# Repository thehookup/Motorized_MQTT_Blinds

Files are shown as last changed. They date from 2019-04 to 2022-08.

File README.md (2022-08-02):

# Motorized_MQTT_Blinds

I forked to add a couple of other base sizes. This is a great project to get the idea of how things work, but the contollers weren't staying connected with my HomeAssistant instance. I ultimately use the hardware from this repo with [Tasmota](https://github.com/tasmota/tasmotizer) configured in [Cover mode](https://tasmota.github.io/docs/Blinds-and-Shutters/#using-stepper-motors) instead. The instructions look daunting, but it takes longer to read than to set up, and it's been running rock solid for months now...

Make sure you use 2208's for noise control, otherwise you can have a rude awakening!

This repository is to accompany my Motorized_MQTT_Blinds video:

IMAGE ALT TEXT HERE (https://www.youtube.com/watch?v=1O_1gUFumQM)

## Parts List
Stepper Motors: https://amzn.to/2D5rVsF

Stepper Drivers: https://amzn.to/2OZqW1W

NodeMCU: https://amzn.to/2I89xDF

12V Power Supply: https://amzn.to/2G2ZJrf

Buck Converter: https://amzn.to/2UsQ7jA

## 3D Printing

Download the correct STL file for your style of tilt rod

## Wiring Schematic

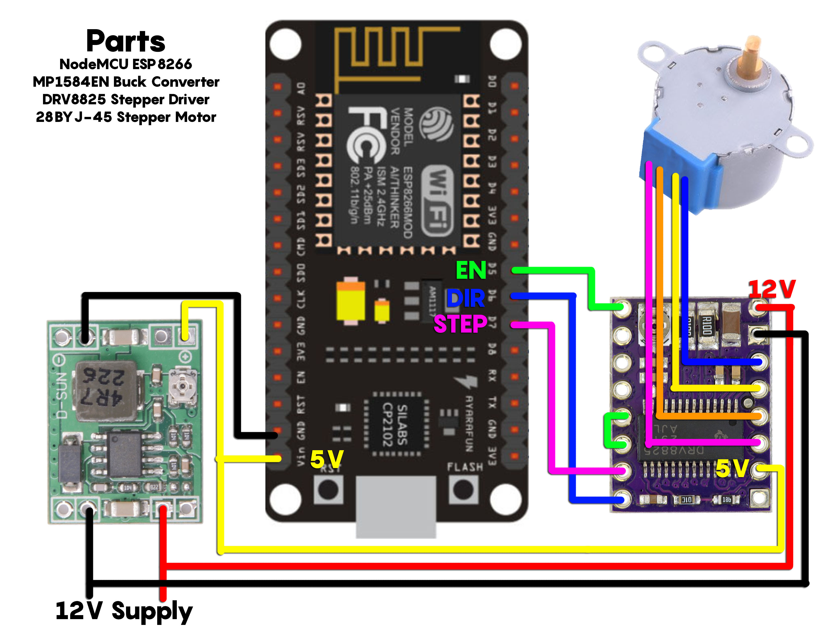
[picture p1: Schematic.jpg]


**Dont forget to cut the center trace on the stepper motor as shown in the youtube video**

## File setup

Fill out the entire USER CONFIGURATION section of the code.

You should leave "STEPS_TO_CLOSE" at 12 to start with.  It can be adjusted for your specific blinds

## Home Assistant YAML

Replace "BlindsMCU" with your MQTT_CLIENT_ID if you changed it in the file setup

Home Assistant 2022.7.5 and Later:
```yaml
mqtt:
  cover:
    - name: "BlindsKitchen"
      command_topic: "BlindsMCU/blindsCommand"
      position_topic: "BlindsMCU/positionState"
      set_position_topic: "BlindsMCU/positionCommand"
      retain: true
      payload_open: "OPEN"
      payload_close: "CLOSE"
      payload_stop: "STOP"
      position_open: 0
      position_closed: 12
```

Home Assistant 2022.6.5 and Earlier:

```yaml
cover:
  - platform: mqtt
    name: "Motorized Blinds"
    command_topic: "BlindsMCU/blindsCommand"
    set_position_topic: "BlindsMCU/positionCommand"
    position_topic: "BlindsMCU/positionState"
    retain: true
    payload_open: "OPEN"
    payload_close: "CLOSE"
    payload_stop: "STOP"
    position_open: 0
    position_closed: 12
  ```
  
## Optional - PCB Design for 3 blind system

Project File: 

GERBER FILE:Sender Board: https://github.com/thehookup/Motorized_MQTT_Blinds/blob/master/THU_Sender_Board.zip

GERBER FILE:Receiver Board: https://github.com/thehookup/Motorized_MQTT_Blinds/blob/master/THU_Receiver_Board.zip

## User Submitted PCBs

GERBER FILE: Dave Morris Quad Blind: https://github.com/thehookup/Motorized_MQTT_Blinds/blob/master/Dave_Morris_4_Blind_With_Power.zip

GERBER FILE:Joshua Garrison Single Blind: https://github.com/thehookup/Motorized_MQTT_Blinds/blob/master/Joshua_Garrison_Single_Blind.zip
  
## Recommended Tools

Ender3 3d Printer: https://amzn.to/2GcznnZ

Dupont Crimper and Connector Set: https://amzn.to/2X1Oeap

## Alexa only support available in the releases tab of this repo!

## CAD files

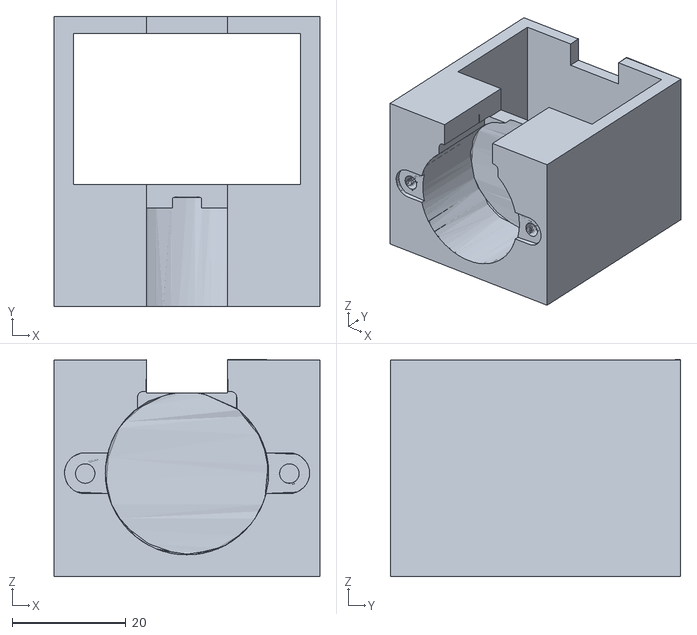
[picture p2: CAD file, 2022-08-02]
BlindsBaseShort.stl
46.8 x 51.1 x 38.2

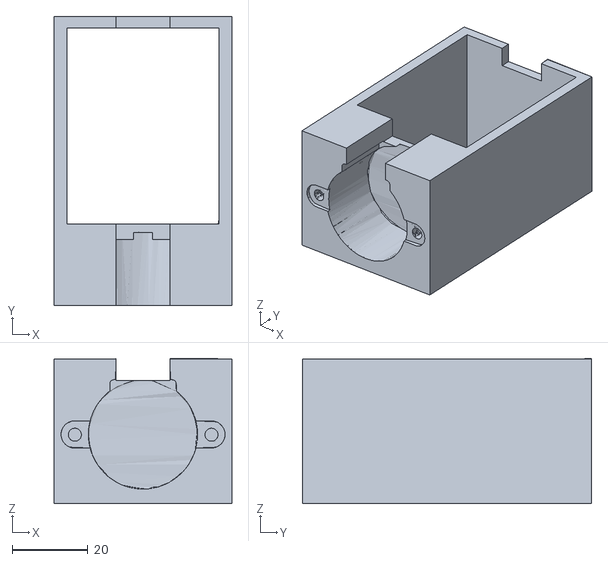
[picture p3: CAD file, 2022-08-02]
BlindsBaseShortLong.stl
46.8 x 76.1 x 38.2

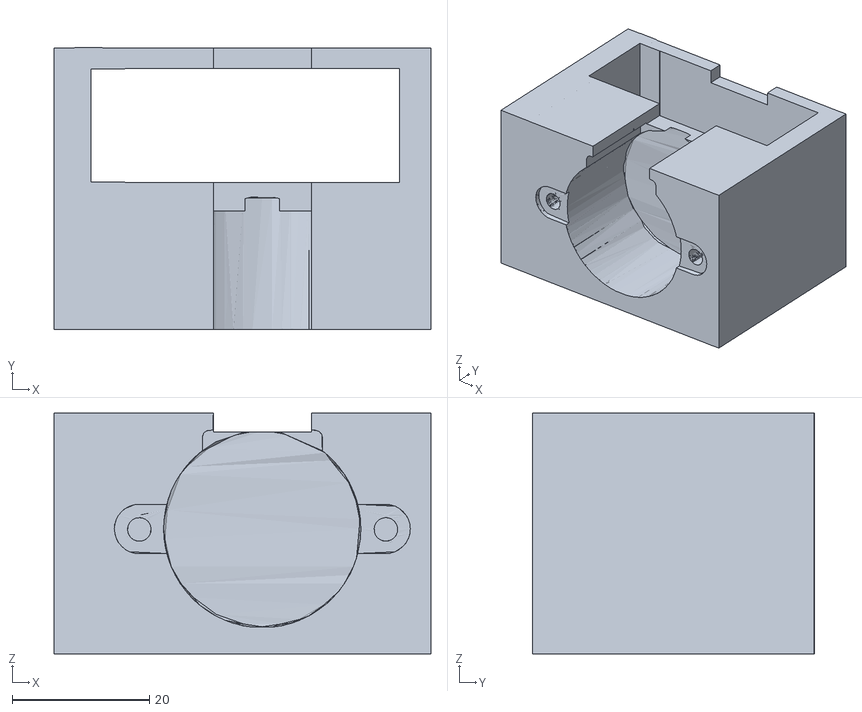
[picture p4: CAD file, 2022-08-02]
123jaloezie-base.stl
55.0 x 41.2 x 35.1

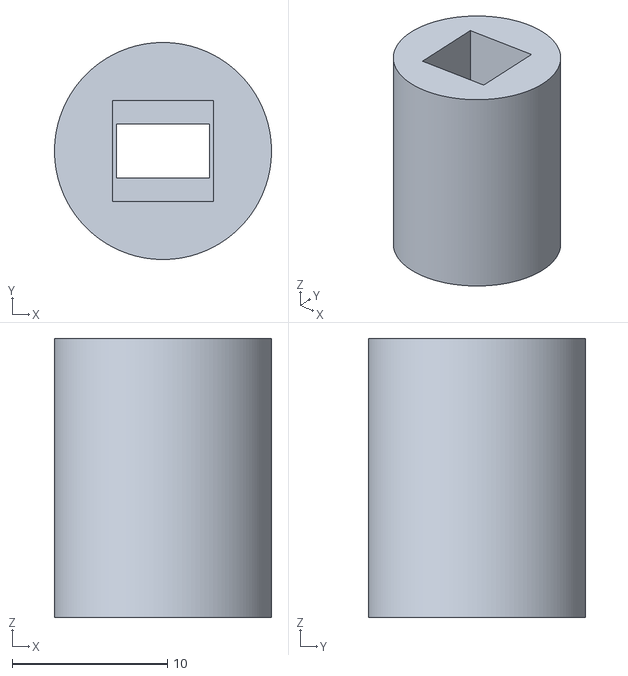
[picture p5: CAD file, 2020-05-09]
BlindsAdapter6mmSquare.stl
14.0 x 14.0 x 18.0

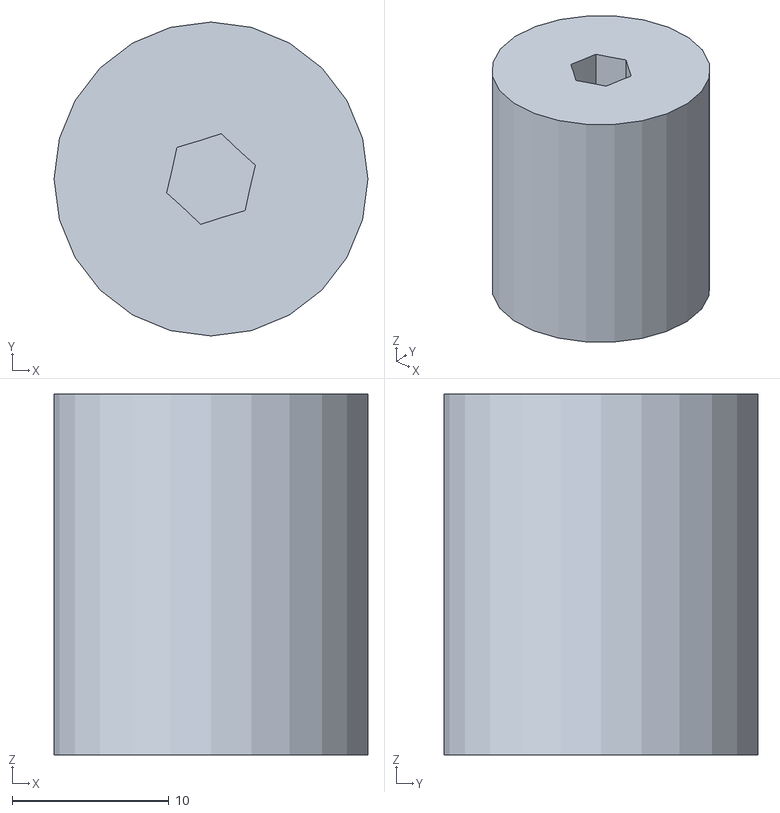
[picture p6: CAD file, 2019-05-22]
Adjusted 5mm Connector.stl
20.0 x 20.0 x 23.0

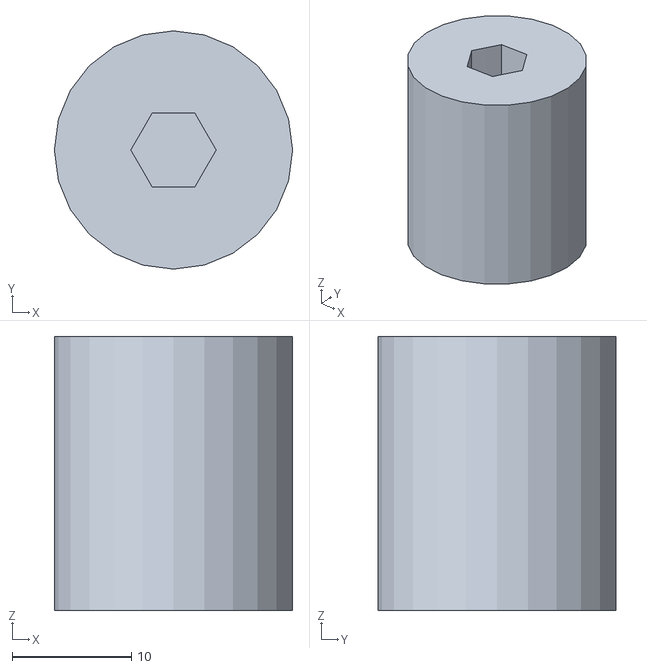
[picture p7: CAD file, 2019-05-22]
Adjusted 6mm Connector.stl
20.0 x 20.0 x 23.0

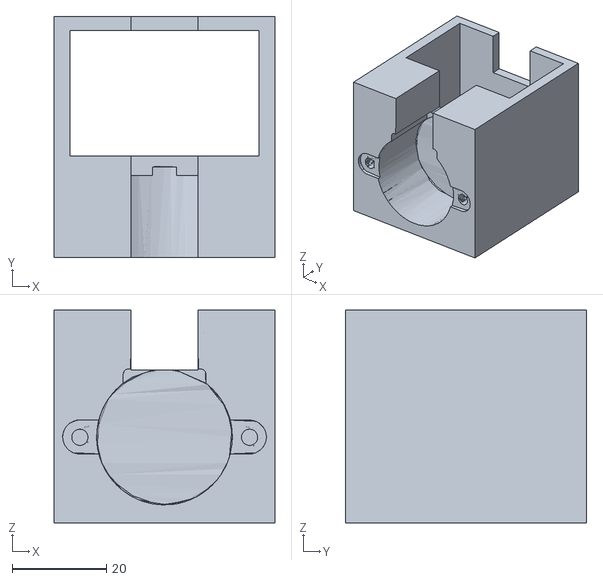
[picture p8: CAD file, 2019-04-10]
BlindsBase.stl
46.8 x 51.1 x 45.1

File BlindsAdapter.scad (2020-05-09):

$fn=144;

shaft_diameter = 6.5;

difference() {
    cylinder(18, 7, 7);
    
    //Blinds shaft
    translate([-shaft_diameter/2, -shaft_diameter/2, 7])
        cube([shaft_diameter, shaft_diameter, 11]);
    
    // Motor shaft
    translate([-6/2, -3.5/2, 0])
        cube([6, 3.5, 7]);
};

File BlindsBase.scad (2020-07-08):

block_z = 22;
block_y = 47;
block_x = 36;
cylinder_cutout_depth = 25;

difference() {
  cube([block_x, block_y, block_z], center=true);
  
  color("blue") translate([0,0,3]) cylinder(r=14.1, h=cylinder_cutout_depth, $fn=100, center=true);
  color("red") translate([5.7,0,6]) cube([17,18,30.5], center=true);
  color("black") translate([10,0,6]) cube([17,15,30.5], center=true);
  
  color("purple") translate([0,17.4,10]) cylinder(r=3.35, h=2, $fn=100);
  color("orange") translate([0,14.05,11]) cube([6.7,6.7,2], center=true);
  
  color("purple") translate([0,-17.4,10]) cylinder(r=3.35, h=2, $fn=100);
  color("orange") translate([0,-14.05,11]) cube([6.7,6.7,2], center=true);

  color("green") translate([0,-17.4,6]) cylinder(r=1.5, h=5, $fn=100);
  color("green") translate([0,17.4,6]) cylinder(r=1.5, h=5, $fn=100);

  // Cut out notches on corners for blind lip.
  color("magenta") translate([-((block_x - 2.5)/2), ((block_y - 2.5)/2), 0]) cylinder(r= (2.5/1), h=block_z, center=true, $fn=100); // cube([2.5, 2.5, block_z], center=true);
  color("magenta") translate([-((block_x - 2.5)/2), -((block_y - 2.5)/2), 0]) cylinder(r= (2.5/1), h=block_z, center=true, $fn=100); // cube([2.5, 2.5, block_z], center=true);
  
  color("cyan") translate([(block_x / 2),0,-(block_z/2)]) cylinder(r=1.5, h=4, $fn=100, center=true);

}

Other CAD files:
BlindsAdapter5mmSquare.stl
BlindsAdapter4mmSquare.stl

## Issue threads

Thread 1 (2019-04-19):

Alexa version issue

nickm324, 2019-04-19:
I dont think the Alexa version in the releases page is actually they Alexa version.
Have you tested this Alexa version? I am getting all kinds of weird results. First the Flasher wouldn't work, as soon as I would click the FLASH button it would instantly say FLASH COMPLETE in a small dialog. So I then decided to use NodeMCU-PyFlasher, which worked. I finally got it to show up on my phone as Blinds Setup so I connected to that AP, set the SSID, password and left 12 in the box. It then said it was going to attempt to connect to the network and that was it no other interaction on the phone from that point. So after I just went ahead and hit the reset NodeMCU to let it reboot although I cant tell what its doing if anything. So then Opened the Alexa App and did a discover devices and chose type as OTHER since I have no idea what type of device its going to show up as. 1 device showed up called "12" as a LIGHT, that is connected via HUE HUB and the type is LIGHT. And it says to say Alexa turn off or on the LIGHT to control it. Then I decided to look at the source code so I downloaded that and opened it up all I see is a bunch of stuff about MQTT and everything in that source looks like its trying to use an MQTT broker to do what ever its trying to do.
Any insight to what I am doing wrong would be greatly appreciated.

thehookup, 2019-04-19:
Resolution posted on youtube comments:

@Nick Marino Ah, yeah, it's the same as mine.  You have mistaken configurable fields for labels.  The "12" should be typed where it says "Rotations 12 Recommended" in gray. SSID should be typed where it says SSID and your password should be below that.  Where you currently have "12" is the spot to type the alexa invocation name.  When you click on a field the gray text disappears.  This isn't my design, it's a pre-made library called WiFiConfig.

Closing this issue.

Closed 2019-04-19.

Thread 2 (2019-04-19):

Feature Request - ZigBee Interface

malarivi, 2019-04-19:
Can you update this to run off zigbee for clean wifi?

thehookup, 2019-04-21:
Unlikely, that would involve adding another radio (Xbee) to the ESP8266, it would be better to use an arduino nano in that case and this code is written for the ESP8266.

Closed 2019-09-21.

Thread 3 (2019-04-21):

Battery

danpowell88, 2019-04-21:
Any chance you could do an update or show an example of the type of battery that would be compatible with this instead of requiring AC power

recklessnl, 2019-06-05:
Seconding this, some locations just have no way of wiring it to AC power without it looking awful.

Additionally, I saw someone using the solar power strips strapped on the glass, which you couldn't see from inside, but they would charge the battery during the day. Is this something that's feasible with this build?

thehookup, 2019-09-21:
I have a working prototype of this, trying to ensure its safety and longevity before I release it into the wild.

tung256, 2019-11-03:
that would be awesome!
i volunteer to be the first to try if the battery can last at least 2 weeks.

incognit-joe, 2019-11-13:
Hi, I have built the kit and have a dual motor set up. Everything running perfectly thanks! I would also be interested in the battery option. Can you advise if you've had any progress with this as i would be pretty gutted if i proceed to drill holes in my walls then a week later you put up a tutorial to add a battery..

Either way i want to extend my thanks, this is the first electronic project i have ever tried and im over the moon to have succeeded!

Rgds,
Joe

thehookup, 2019-11-13:
In my initial test the battery only lasted 2 months, even with the solar panels on it.  I need to revamp the code a bit more but currently have no time to devote to it.  Probably in mid-december I'll revisit.

joelwetzel, 2020-02-21:
Any updates?  I've built 2 of these awesome things now.  But would love to get rid of more cables.

1ntroduc3, 2020-07-26:
> In my initial test the battery only lasted 2 months, even with the solar panels on it. I need to revamp the code a bit more but currently have no time to devote to it. Probably in mid-december I'll revisit.

Do you have any update?

JustMaier, 2020-09-09:
@thehookup Any chance you can at least share a few of the details on what components you used and maybe what adjustments you made? 2 months on battery is actually pretty good.

I'm going to attempt the battery-powered route here's my plan.

**Additional Components:**
- 5000mAh USB battery pack
- [7 Solar Cells (60mA)](https://smile.amazon.com/gp/product/B0736W4HK1) + [Schottky Diodes](https://smile.amazon.com/gp/product/B079KDQQPD) (to bypass dark cells) (anticipating 70mA - 210mA total)
- Micro USB cable to recharge battery pack from 5V from solar cells
- [Step Up Converter (5v to 12v)](https://smile.amazon.com/gp/product/B07RNBJK5F) between the battery pack and driver (since my base power will be 5V, I plan on dropping the buck converter)

**Code Adjustments:**
- [Modem sleep](https://diyi0t.com/how-to-reduce-the-esp8266-power-consumption) the device and wake it every 5 seconds to check for MQTT messages. _Optimally_ reduces daily power consumption by ~60% (80% of every minute it's running at 25mA instead of 100mA)
- Auto close and deep sleep from 8pm - 8am. _Hopefully_ reduces daily power consumption by an additional ~37% (I believe it still consumes 10mA in this mode)
- Assign static IP (reduces the power needed on wake)

**Hopeful Outcome:**
- - 600mAh/day for nodemcu
- -5mAh/day for motor (assuming 1.25mAh per open or close with 4 operations per day)
- +560mAh on bad days or +1,680mAh on good days from solar cells

**Potential Problems:**
- Solar is likely to underperform what I've hoped for. I tried to measure output with a multimeter on my desired windows and a single cell was producing 3mA at noon on a sunny day which is considerably less than even my "bad day" estimate. Maybe different panels would help, or maybe my window just doesn't get enough light... Either way, if I'm only able to get 168mAh/day from the cells, I can only expect to go 10 days or so without having to recharge
- I haven't accurately measured the consumption of the actual motors to open and close the blinds. I figure they'll only be used 2-4 times a day and I'm hoping that I can essentially just not worry about their overall power draw with such limited use. That assumption could be very wrong.
- Sleep cycling the nodemcu like that might not actually save as much energy as I hope
- I'll probably have to tweak the USB battery pack so that it doesn't turn off when the nodemcu deep sleeps
- I've never done something like this before and I could be horribly horribly wrong with all my calculations and components needed 😂

Mehick57, 2021-05-04:
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

Sounds like a great idea and plan! I am just wondering if you have gotten this to work? This is exactly what I am looking for since I can't run wires to ten sets of blinds I would like to convert! Thanks for your time!

Mehick57, 2021-05-04:
> In my initial test the battery only lasted 2 months, even with the solar panels on it. I need to revamp the code a bit more but currently have no time to devote to it. Probably in mid-december I'll revisit.

It would be great if one of you geniuses could figure this one out!

JustMaier, 2021-05-04:
> > In my initial test the battery only lasted 2 months, even with the solar panels on it. I need to revamp the code a bit more but currently have no time to devote to it. Probably in mid-december I'll revisit.
>
> It would be great if one of you geniuses could figure this one out!

I actually abandoned this route. In my findings, it seemed that WiFi takes too much energy to be able to run on a battery for an extended period of time.

The best way to do this in my research was actually using RF on a micro-controller designed for low-power usage, like a moteino. This was a [helpful guide project](https://snorp.net/2016/05/20/blinds-controller.html).

Mehick57, 2021-05-05:
Thanks so much for your
          quick reply and being pointed towards this project! I will be
          trying to see if I can put this together and get it working on
          HA!

    On 5/4/2021 4:54 PM, Justin Maier
      wrote:

          In my initial test the battery only lasted 2 months, even
            with the solar panels on it. I need to revamp the code a bit
            more but currently have no time to devote to it. Probably in
            mid-december I'll revisit.

        It would be great if one of you geniuses could figure this
          one out!

      I actually abandoned this route. In my findings, it seemed that
        WiFi takes too much energy to be able to run on a battery for an
        extended period of time.
      The best way to do this in my research was actually using RF on
        a micro-controller designed for low-power usage, like a moteino.
        This was a helpful guide project.
      —
        You are receiving this because you commented.
        Reply to this email directly, view it on GitHub, or unsubscribe.
      [
{
***@***.***": "http://schema.org",
***@***.***": "EmailMessage",
"potentialAction": {
***@***.***": "ViewAction",
"target": "https://github.com/thehookup/Motorized_MQTT_Blinds/issues/3#issuecomment-832275991",
"url": "https://github.com/thehookup/Motorized_MQTT_Blinds/issues/3#issuecomment-832275991",
"name": "View Issue"
},
"description": "View this Issue on GitHub",
"publisher": {
***@***.***": "Organization",
"name": "GitHub",
"url": "https://github.com"
}
}
]

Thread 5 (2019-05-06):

Smartthings integration

mbecraft76, 2019-05-06:
Flashed your bin file for the Smartthings integration. Flash went fine on a brand new nodemcu board. Parent device created properly as I've created a dozen or so with the ST Anything parent/child devices. The nodemcu board seems to connect to smartthings just fine, Refresh works just fine. It shows up in the Smartthings log when refreshed. But no child devices have been created. Which ST Anything child device is this supposed to take advantage of? The available ones from Dan/Daniel don't seem to support the stepper motors.

CurtisFeatures, 2019-09-16:
>Flashed your bin file for the Smartthings integration. Flash went fine on a brand new nodemcu board. Parent device created properly as I've created a dozen or so with the ST Anything parent/child devices. The nodemcu board seems to connect to smartthings just fine, Refresh works just fine. It shows up in the Smartthings log when refreshed. But no child devices have been created. Which ST Anything child device is this supposed to take advantage of? The available ones from Dan/Daniel don't seem to support the stepper motors.

@mbecraft76 did you manage to get this going? I’ve also been unable to get it working today

<sub>Sent with <a href="http://githawk.com">GitHawk</a></sub>

mbecraft76, 2019-09-16:
@CurtisFeatures  no I never got it going. I posted here and posted on Reddit where I first saw this project. I may have even posted on youtube about it, I don't remember. All I got was crickets. I'm not sure if this guy even cares about the smartthings integration. Dude has some decent ideas, but followup and finesse need a lot more work. All I know is that I wasted my money on parts for this and ended up using the ST Anything servo libraries and a few servos instead. I also 3D printed adapters for the servos to fit in the blinds. They were cheaper and easier to use anyway. No janky process of cutting traces like on the stepper motors or adding buck converters or driver boards. I'm sure the stepper motors are quieter, but I really don't care about the noise. If you'd like, I can point you to the posts/threads on smartthings that I used to make mine work. If someone ever comes up with a reliable stepper motor library that integrates with ST Anything, I may swap over to them just to compare.

CurtisFeatures, 2019-09-16:
>@CurtisFeatures  no I never got it going. I posted here and posted on Reddit where I first saw this project. I may have even posted on youtube about it, I don't remember. All I got was crickets. I'm not sure if this guy even cares about the smartthings integration. Dude has some decent ideas, but followup and finesse need a lot more work. All I know is that I wasted my money on parts for this and ended up using the ST Anything servo libraries and a few servos instead. I also 3D printed adapters for the servos to fit in the blinds. They were cheaper and easier to use anyway. No janky process of cutting traces like on the stepper motors or adding buck converters or driver boards. I'm sure the stepper motors are quieter, but I really don't care about the noise. If you'd like, I can point you to the posts/threads on smartthings that I used to make mine work. If someone ever comes up with a reliable stepper motor library that integrates with ST Anything, I may swap over to them just to compare.

@mbecraft76 I got it working with MQTT and openHAB for home use and it’s been working fine. I also made my own 3D printed enclosure as I use it with virtue or blinds so need around 150 steps to open the blinds. I also got it working with Alexa (for friends) but this was a pain and took a lot of trial and error due to poor instructions (see my closed issue). I just thought it would be a lot easier and better to use with the smart things hub but it wasn’t the out of the box experience I was expecting like it was with Alexa. I wish google would be more open so we can integrate directly with the esp chips.

<sub>Sent with <a href="http://githawk.com">GitHawk</a></sub>

thehookup, 2019-09-21:
The ST integration works, but needs to be coded in arduino.  The WiFiManager version of it won't work due to the way that the STAnywhere library initializes the server.

The .ino file for smart things is in this repo.  Unless I rewrite ST anywhere (not likely) or it is updated to work with wifimanager it will be the only way to use ST.

xHirscHx, 2020-02-05:
Same boat as above with ST bin. So i got it working with Alexa bin. but really want it to run in ST.
If the wifi manager intructions dont work for ST. Are there instructions how to "but needs to be coded in arduino" Im more of a hardware guy and copy and pastier.
thx

CurtisFeatures, 2020-02-05:
I could never get it going with ST even using Arduino IDE. In the end iv gone back to MQTT and its all setup in my openhab server - I just like things to have hubs in case the openhab server goes down things still work.

ryancasler, 2020-06-25:
If it's only a question of a Child DTH for ST_Anything, I just need a clear understanding of what information the board is expecting to receive and what it is going to send back to the hub.  Is sketch expecting just a raw integer with nothing else before or after to identify it?  Or is it also expecting to receive the current position every time it receives a command?  What type of acknowledgement that the order has been received will be received back after the POST request is sent to the board?  Typically, that is when the event is created in ST to update the device in the ST database, not when the command is sent.  For example, when commanding a switch to turn on with ST_Anything, the HTTP POST will be sent to an endpoint like this:
`http://ip.of.board:8090/switch1%20on?`
The "?" is used as a built-in "end of message" character and if you don't include that, a stoock ST anything board won't recognize the command.  Conversely, if you are trying to use a stock ST_Anything DTH and the sketch is not expecting the ? at the end, the board won't recognize the command being sent to it.  A few more details on what http strings will be send back and forth is all I need to be able to code a DTH in Groovy for ST or Hubitat.  I can't completely tell since MQTT is still fairly new to me.  However, I am fairly familiar with ST_Anything (Hubduino) and have written several DTH for it.  Also, there are some example sketches in the ST_Anything library which only use the SmartThings ESP8266 Wifi library.  These might be of some help in adapting the sketch to more closely follow the standards.  I'll take a look at it later today or tomorrow and see what I can come up with.
I've just ordered a set of motors and drivers as I'm looking to change a couple of my servo controlled blinds over to running with the steppers in hopes of getting them to close more tightly.

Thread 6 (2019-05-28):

New 3D Printed Servo Holder

cheechie, 2019-05-28:
My blinds (from Home Depot) are slightly different so I had to make a new servo holder.  Here is the STL file.  https://www.thingiverse.com/thing:3658592

tonydahtiger, 2019-05-28:
I am doing the same for my Bali wooden blinds.

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

cmille34, 2019-08-04:
Thanks @cheechie for taking the time to post your holder.  Worked great for my blinds as well.

tung256, 2019-10-20:
@cheechie , could you please take a picture of your blinds? i got mine from HD and i just want to make sure. also, when you print the STL file, are the units of measurement in mm, cm, or inches? thanks!

tung256, 2019-10-30:
i missed it by 1cm using the STL file he posted.  is that the same issue you experienced?
https://i.imgur.com/wSi4AtZ.jpg

cheechie, 2019-11-01:
can you just slide the servo closer.  Thats all I had to do.

Here is a picture of mine.  https://ibb.co/QrtFVKD

tung256, 2019-11-01:
it is already close but wont fit because the motor is 1cm higher than the hex stick.

tung256, 2019-11-03:
i just printed your modified STL file and i am happy to say it fits like a glove! wow.
here it is in its new home  https://i.imgur.com/D0F5GWl.jpg
thanks for posting.

v-yarotsky, 2020-04-26:
Thank you for posting @cheechie! And thank you @thehookup for this awesome guide!
I needed to make some tweaks for my home depot blinds, but so far so good :)
In case anyone needs them, here are my customizations: https://www.thingiverse.com/thing:4314465

echojjj, 2020-05-13:
Thank you @cheechie!  This fits perfectly!  Did you have to change the rotations from 12 to something else?

JoshuaGarrison27, 2021-01-12:
@cheechie Thank you. This fit snuggly in my blinds!

Davidadragoo, 2022-01-24:
This also solved my fit problem, thanks for sharing!

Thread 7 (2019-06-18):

Having Trouble with variables

morgancrawford6, 2019-06-18:
Not sure what I am doing wrong. This is the error  get

Arduino: 1.8.9 (Mac OS X), Board: "Generic ESP8266 Module, 80 MHz, Flash, Disabled, All SSL ciphers (most compatible), ck, 26 MHz, 40MHz, DOUT (compatible), 512K (no SPIFFS), 2, nonos-sdk 2.2.1 (legacy), v2 Lower Memory, Disabled, None, Only Sketch, 115200"

Blinds_CONFIGURE_Portal_Alexa:36:35: error: 'D6' was not declared in this scope
 #define STEPPER_DIR_PIN           D6
                                   ^
/Users/Morgan/Desktop/Motorized_MQTT_Blinds-ee901ad7f0b51b0aa66704f191ce5e89c597226d/Blinds_CONFIGURE_Portal_Alexa/Blinds_CONFIGURE_Portal_Alexa.ino:51:51: note: in expansion of macro 'STEPPER_DIR_PIN'
 AH_EasyDriver shadeStepper(STEPPER_STEPS_PER_REV, STEPPER_DIR_PIN ,STEPPER_STEP_PIN,STEPPER_MICROSTEP_1_PIN,STEPPER_MICROSTEP_2_PIN,STEPPER_SLEEP_PIN);
                                                   ^
Blinds_CONFIGURE_Portal_Alexa:37:35: error: 'D7' was not declared in this scope
 #define STEPPER_STEP_PIN          D7
                                   ^
/Users/Morgan/Desktop/Motorized_MQTT_Blinds-ee901ad7f0b51b0aa66704f191ce5e89c597226d/Blinds_CONFIGURE_Portal_Alexa/Blinds_CONFIGURE_Portal_Alexa.ino:51:68: note: in expansion of macro 'STEPPER_STEP_PIN'
 AH_EasyDriver shadeStepper(STEPPER_STEPS_PER_REV, STEPPER_DIR_PIN ,STEPPER_STEP_PIN,STEPPER_MICROSTEP_1_PIN,STEPPER_MICROSTEP_2_PIN,STEPPER_SLEEP_PIN);
                                                                    ^
Blinds_CONFIGURE_Portal_Alexa:38:35: error: 'D5' was not declared in this scope
 #define STEPPER_SLEEP_PIN         D5
                                   ^
/Users/Morgan/Desktop/Motorized_MQTT_Blinds-ee901ad7f0b51b0aa66704f191ce5e89c597226d/Blinds_CONFIGURE_Portal_Alexa/Blinds_CONFIGURE_Portal_Alexa.ino:51:133: note: in expansion of macro 'STEPPER_SLEEP_PIN'
 AH_EasyDriver shadeStepper(STEPPER_STEPS_PER_REV, STEPPER_DIR_PIN ,STEPPER_STEP_PIN,STEPPER_MICROSTEP_1_PIN,STEPPER_MICROSTEP_2_PIN,STEPPER_SLEEP_PIN);
                                                                                                                                     ^
/Users/Morgan/Desktop/Motorized_MQTT_Blinds-ee901ad7f0b51b0aa66704f191ce5e89c597226d/Blinds_CONFIGURE_Portal_Alexa/Blinds_CONFIGURE_Portal_Alexa.ino: In function 'void configPortal()':
Blinds_CONFIGURE_Portal_Alexa:157:18: error: 'D1' was not declared in this scope
   if(digitalRead(D1) == LOW)
                  ^
/Users/Morgan/Desktop/Motorized_MQTT_Blinds-ee901ad7f0b51b0aa66704f191ce5e89c597226d/Blinds_CONFIGURE_Portal_Alexa/Blinds_CONFIGURE_Portal_Alexa.ino: In function 'void setup()':
Blinds_CONFIGURE_Portal_Alexa:267:11: error: 'D1' was not declared in this scope
   pinMode(D1, INPUT_PULLUP);
           ^
exit status 1
'D6' was not declared in this scope

This report would have more information with
"Show verbose output during compilation"
option enabled in File -> Preferences.

thehookup, 2019-06-22:
You are trying to flash using the "Generic ESP8266" board definition, not the NodeMCU, select nodemcu and the D6 and other definitions will be there.

Closed 2019-09-21.

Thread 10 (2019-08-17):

Alexa not discovering

CurtisFeatures, 2019-08-17:
Hi, great work here as usual. I wonder if you could help, I have been using the MQTT blinds and it’s been working great. I’m trying to try out the Alexa version but having issues. I can flash the board and connect it to my WiFi giving it a name and everything. I can ping it so I know it’s connected to the WiFi however I’m unable to discover it in the Alexa app. I thought it might have been my WiFi at work causing issues but I’ve brought it home and reflagged and get the same issue here. I’ve never used Alexa before (google fan boy) so I’m not sure if I’m missing something.

CurtisFeatures, 2019-08-21:
Iv made a bit of progress with this. I thought I would try flashing the fauxmoESP code onto the ESP8226 to see if I could get that to work. I didn't and had the same issues. Then I came across this issue post on BitBucket https://bitbucket.org/xoseperez/fauxmoesp/issues/58/v30-not-discovered-by-alexa with people having the same issue. Once I rolled back my board manager to 2.3.0 and changed by board rate to flash I was able to discover my device.

Now when I try to compile the hook ups code with the 2.3.0 board manager I'm getting a lot of error to do with WiFimanger and Webserver but I think this might be to do with mismatched versions so im going to try roll some of those back and see if it works.

CurtisFeatures, 2019-08-21:
This is my output if anyone can help:

`

/Users/jamiecurtis/Documents/Arduino/libraries/WiFiManager-0.14/WiFiManager.cpp: In member function 'void WiFiManager::setupConfigPortal()':
/Users/jamiecurtis/Documents/Arduino/libraries/WiFiManager-0.14/WiFiManager.cpp:146:71: error: no matching function for call to 'ESP8266WebServer::on(String, std::_Bind_helper<false, void (WiFiManager::*)(), WiFiManager* const>::type)'
   server->on(String(F("/")), std::bind(&WiFiManager::handleRoot, this));
                                                                       ^
/Users/jamiecurtis/Documents/Arduino/libraries/WiFiManager-0.14/WiFiManager.cpp:146:71: note: candidates are:
In file included from /Users/jamiecurtis/Documents/Arduino/libraries/WiFiManager-0.14/WiFiManager.h:17:0,
                 from /Users/jamiecurtis/Documents/Arduino/libraries/WiFiManager-0.14/WiFiManager.cpp:13:
/Users/jamiecurtis/Library/Arduino15/packages/esp8266/hardware/esp8266/2.3.0/libraries/ESP8266WebServer/src/ESP8266WebServer.h:79:8: note: void ESP8266WebServer::on(const char*, ESP8266WebServer::THandlerFunction)
   void on(const char* uri, THandlerFunction handler);
        ^
/Users/jamiecurtis/Library/Arduino15/packages/esp8266/hardware/esp8266/2.3.0/libraries/ESP8266WebServer/src/ESP8266WebServer.h:79:8: note:   no known conversion for argument 1 from 'String' to 'const char*'
/Users/jamiecurtis/Library/Arduino15/packages/esp8266/hardware/esp8266/2.3.0/libraries/ESP8266WebServer/src/ESP8266WebServer.h:80:8: note: void ESP8266WebServer::on(const char*, HTTPMethod, ESP8266WebServer::THandlerFunction)
   void on(const char* uri, HTTPMethod method, THandlerFunction fn);
        ^
/Users/jamiecurtis/Library/Arduino15/packages/esp8266/hardware/esp8266/2.3.0/libraries/ESP8266WebServer/src/ESP8266WebServer.h:80:8: note:   candidate expects 3 arguments, 2 provided
/Users/jamiecurtis/Library/Arduino15/packages/esp8266/hardware/esp8266/2.3.0/libraries/ESP8266WebServer/src/ESP8266WebServer.h:81:8: note: void ESP8266WebServer::on(const char*, HTTPMethod, ESP8266WebServer::THandlerFunction, ESP8266WebServer::THandlerFunction)
   void on(const char* uri, HTTPMethod method, THandlerFunction fn, THandlerFunction ufn);
        ^
/Users/jamiecurtis/Library/Arduino15/packages/esp8266/hardware/esp8266/2.3.0/libraries/ESP8266WebServer/src/ESP8266WebServer.h:81:8: note:   candidate expects 4 arguments, 2 provided
/Users/jamiecurtis/Documents/Arduino/libraries/WiFiManager-0.14/WiFiManager.cpp:147:81: error: no matching function for call to 'ESP8266WebServer::on(String, std::_Bind_helper<false, void (WiFiManager::*)(unsigned char), WiFiManager* const, bool>::type)'
   server->on(String(F("/wifi")), std::bind(&WiFiManager::handleWifi, this, true));
                                                                                 ^
/Users/jamiecurtis/Documents/Arduino/libraries/WiFiManager-0.14/WiFiManager.cpp:147:81: note: candidates are:
In file included from /Users/jamiecurtis/Documents/Arduino/libraries/WiFiManager-0.14/WiFiManager.h:17:0,
                 from /Users/jamiecurtis/Documents/Arduino/libraries/WiFiManager-0.14/WiFiManager.cpp:13:
/Users/jamiecurtis/Library/Arduino15/packages/esp8266/hardware/esp8266/2.3.0/libraries/ESP8266WebServer/src/ESP8266WebServer.h:79:8: note: void ESP8266WebServer::on(const char*, ESP8266WebServer::THandlerFunction)
   void on(const char* uri, THandlerFunction handler);
        ^
/Users/jamiecurtis/Library/Arduino15/packages/esp8266/hardware/esp8266/2.3.0/libraries/ESP8266WebServer/src/ESP8266WebServer.h:79:8: note:   no known conversion for argument 1 from 'String' to 'const char*'
/Users/jamiecurtis/Library/Arduino15/packages/esp8266/hardware/esp8266/2.3.0/libraries/ESP8266WebServer/src/ESP8266WebServer.h:80:8: note: void ESP8266WebServer::on(const char*, HTTPMethod, ESP8266WebServer::THandlerFunction)
   void on(const char* uri, HTTPMethod method, THandlerFunction fn);
        ^
/Users/jamiecurtis/Library/Arduino15/packages/esp8266/hardware/esp8266/2.3.0/libraries/ESP8266WebServer/src/ESP8266WebServer.h:80:8: note:   candidate expects 3 arguments, 2 provided
/Users/jamiecurtis/Library/Arduino15/packages/esp8266/hardware/esp8266/2.3.0/libraries/ESP8266WebServer/src/ESP8266WebServer.h:81:8: note: void ESP8266WebServer::on(const char*, HTTPMethod, ESP8266WebServer::THandlerFunction, ESP8266WebServer::THandlerFunction)
   void on(const char* uri, HTTPMethod method, THandlerFunction fn, THandlerFunction ufn);
        ^
/Users/jamiecurtis/Library/Arduino15/packages/esp8266/hardware/esp8266/2.3.0/libraries/ESP8266WebServer/src/ESP8266WebServer.h:81:8: note:   candidate expects 4 arguments, 2 provided
/Users/jamiecurtis/Documents/Arduino/libraries/WiFiManager-0.14/WiFiManager.cpp:148:83: error: no matching function for call to 'ESP8266WebServer::on(String, std::_Bind_helper<false, void (WiFiManager::*)(unsigned char), WiFiManager* const, bool>::type)'
   server->on(String(F("/0wifi")), std::bind(&WiFiManager::handleWifi, this, false));
                                                                                   ^
/Users/jamiecurtis/Documents/Arduino/libraries/WiFiManager-0.14/WiFiManager.cpp:148:83: note: candidates are:
In file included from /Users/jamiecurtis/Documents/Arduino/libraries/WiFiManager-0.14/WiFiManager.h:17:0,
                 from /Users/jamiecurtis/Documents/Arduino/libraries/WiFiManager-0.14/WiFiManager.cpp:13:
/Users/jamiecurtis/Library/Arduino15/packages/esp8266/hardware/esp8266/2.3.0/libraries/ESP8266WebServer/src/ESP8266WebServer.h:79:8: note: void ESP8266WebServer::on(const char*, ESP8266WebServer::THandlerFunction)
   void on(const char* uri, THandlerFunction handler);
        ^
/Users/jamiecurtis/Library/Arduino15/packages/esp8266/hardware/esp8266/2.3.0/libraries/ESP8266WebServer/src/ESP8266WebServer.h:79:8: note:   no known conversion for argument 1 from 'String' to 'const char*'
/Users/jamiecurtis/Library/Arduino15/packages/esp8266/hardware/esp8266/2.3.0/libraries/ESP8266WebServer/src/ESP8266WebServer.h:80:8: note: void ESP8266WebServer::on(const char*, HTTPMethod, ESP8266WebServer::THandlerFunction)
   void on(const char* uri, HTTPMethod method, THandlerFunction fn);
        ^
/Users/jamiecurtis/Library/Arduino15/packages/esp8266/hardware/esp8266/2.3.0/libraries/ESP8266WebServer/src/ESP8266WebServer.h:80:8: note:   candidate expects 3 arguments, 2 provided
/Users/jamiecurtis/Library/Arduino15/packages/esp8266/hardware/esp8266/2.3.0/libraries/ESP8266WebServer/src/ESP8266WebServer.h:81:8: note: void ESP8266WebServer::on(const char*, HTTPMethod, ESP8266WebServer::THandlerFunction, ESP8266WebServer::THandlerFunction)
   void on(const char* uri, HTTPMethod method, THandlerFunction fn, THandlerFunction ufn);
        ^
/Users/jamiecurtis/Library/Arduino15/packages/esp8266/hardware/esp8266/2.3.0/libraries/ESP8266WebServer/src/ESP8266WebServer.h:81:8: note:   candidate expects 4 arguments, 2 provided
/Users/jamiecurtis/Documents/Arduino/libraries/WiFiManager-0.14/WiFiManager.cpp:149:83: error: no matching function for call to 'ESP8266WebServer::on(String, std::_Bind_helper<false, void (WiFiManager::*)(), WiFiManager* const>::type)'
   server->on(String(F("/wifisave")), std::bind(&WiFiManager::handleWifiSave, this));
                                                                                   ^
/Users/jamiecurtis/Documents/Arduino/libraries/WiFiManager-0.14/WiFiManager.cpp:149:83: note: candidates are:
In file included from /Users/jamiecurtis/Documents/Arduino/libraries/WiFiManager-0.14/WiFiManager.h:17:0,
                 from /Users/jamiecurtis/Documents/Arduino/libraries/WiFiManager-0.14/WiFiManager.cpp:13:
/Users/jamiecurtis/Library/Arduino15/packages/esp8266/hardware/esp8266/2.3.0/libraries/ESP8266WebServer/src/ESP8266WebServer.h:79:8: note: void ESP8266WebServer::on(const char*, ESP8266WebServer::THandlerFunction)
   void on(const char* uri, THandlerFunction handler);
        ^
/Users/jamiecurtis/Library/Arduino15/packages/esp8266/hardware/esp8266/2.3.0/libraries/ESP8266WebServer/src/ESP8266WebServer.h:79:8: note:   no known conversion for argument 1 from 'String' to 'const char*'
/Users/jamiecurtis/Library/Arduino15/packages/esp8266/hardware/esp8266/2.3.0/libraries/ESP8266WebServer/src/ESP8266WebServer.h:80:8: note: void ESP8266WebServer::on(const char*, HTTPMethod, ESP8266WebServer::THandlerFunction)
   void on(const char* uri, HTTPMethod method, THandlerFunction fn);
        ^
/Users/jamiecurtis/Library/Arduino15/packages/esp8266/hardware/esp8266/2.3.0/libraries/ESP8266WebServer/src/ESP8266WebServer.h:80:8: note:   candidate expects 3 arguments, 2 provided
/Users/jamiecurtis/Library/Arduino15/packages/esp8266/hardware/esp8266/2.3.0/libraries/ESP8266WebServer/src/ESP8266WebServer.h:81:8: note: void ESP8266WebServer::on(const char*, HTTPMethod, ESP8266WebServer::THandlerFunction, ESP8266WebServer::THandlerFunction)
   void on(const char* uri, HTTPMethod method, THandlerFunction fn, THandlerFunction ufn);
        ^
/Users/jamiecurtis/Library/Arduino15/packages/esp8266/hardware/esp8266/2.3.0/libraries/ESP8266WebServer/src/ESP8266WebServer.h:81:8: note:   candidate expects 4 arguments, 2 provided
/Users/jamiecurtis/Documents/Arduino/libraries/WiFiManager-0.14/WiFiManager.cpp:150:72: error: no matching function for call to 'ESP8266WebServer::on(String, std::_Bind_helper<false, void (WiFiManager::*)(), WiFiManager* const>::type)'
   server->on(String(F("/i")), std::bind(&WiFiManager::handleInfo, this));
                                                                        ^
/Users/jamiecurtis/Documents/Arduino/libraries/WiFiManager-0.14/WiFiManager.cpp:150:72: note: candidates are:
In file included from /Users/jamiecurtis/Documents/Arduino/libraries/WiFiManager-0.14/WiFiManager.h:17:0,
                 from /Users/jamiecurtis/Documents/Arduino/libraries/WiFiManager-0.14/WiFiManager.cpp:13:
/Users/jamiecurtis/Library/Arduino15/packages/esp8266/hardware/esp8266/2.3.0/libraries/ESP8266WebServer/src/ESP8266WebServer.h:79:8: note: void ESP8266WebServer::on(const char*, ESP8266WebServer::THandlerFunction)
   void on(const char* uri, THandlerFunction handler);
        ^
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
CurtisFeatures, 2019-08-22:
Got it working:

Board Manager: 2.3.0
WiFi Manager: 0.12.0
fauxmoESP: 3.1.0
Upload Speed:  230400
Must have an Echo device to discover within App. Will not work with only App discovery.

Hope this will help other people.

Closed 2019-08-22.

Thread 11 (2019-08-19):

Be sure to cut solder bridge in motors!

mllockwood, 2019-08-19:
I know that it's covered in the YouTube video, but it should probably be added to the list of written instructions.  For those like me that watched the video last week, received our components from Amazon this week, and finally got some time to work on the project... and forgot about that one IMPORTANT step.

Be sure to open up the motor housing and cut the board to eliminate the connection of the red wire on the circuit board.  If you don't the motors will get VERY hot and can be dangerous.

thehookup, 2019-09-21:
Added to the readme, thanks.

Closed 2019-09-21.

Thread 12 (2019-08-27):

Motor not turning

cvetand, 2019-08-27:
I followed the wiring diagram but I can't get the motor to work with the DRV8825. I'm thinking it is a power issue as the specs for the DRV8825 list its minimum operational voltage as 8V where I am getting ~4.2V from the nodemcu and even less with the buck converter. Is the buck converter used to convert the 5V from the nodemcu to 12V or is there a separate power supply that isn't listed?

cmille34, 2019-08-30:
The way I understand the diagrams and the way I have it working is splitting the wires coming from the 12v power supply with one pair of the wires going to the buck converter to convert the 12v from the power supply into a 5v source for the nodeMCU and the DRV8825, then take the other spliced 12v power wires and run them also to the pins on the DRV8825.  Essentially you are providing a 5v and 12v source to the DRV8825.  The motor will use the 12v pins and the driver itself will use the 5v provided to is (I think). The diagram helped me immensely.
https://github.com/thehookup/Motorized_MQTT_Blinds/blob/master/Schematic.jpg

cvetand, 2019-09-15:
That makes sense. I completely missed the 12V power supply in the parts list so the "12V Supply" in the schematic seemed like it was the output of the buck converter. After adding it, it all started to work. Thanks!

Closed 2019-09-15.

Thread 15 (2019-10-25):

One Direction Motor

JoshuaGarrison27, 2019-10-25:
Hey! I got everything wired up and it responds to the MQTT calls and everything but for some reason, the motor only turns in one direction. I have no idea what would cause it to do this. I made sure that I severed the middle contact point on the motor like in the video, double-checked my wiring, and made sure I didn't change much in the Arduino sketch.

Any suggestions?

tung256, 2019-10-27:
i cant even compile the sketch and got bunch of errors as seen [here](https://drive.google.com/open?id=1-4yFY0elkVA2TDw5ZViSLAGbrf280FqB).   this is my first time with Arduino. any idea?
my additional board manager in preferences is: http://arduino.esp8266.com/stable/package_esp8266com_index.json.
In board manager, i have esp8266 by esp8266 community version 2.5.2.

JoshuaGarrison27, 2019-10-27:
@tung256 make sure you have the right libraries installed and board selected

tung256, 2019-10-28:
yes. i got all those .h and .cpp files.
BUT i still cant compile and getting this error:
C:\Program Files (x86)\Arduino\libraries\blinds\ArduinoOTA.cpp:189:34: error: 'U_FS' was not declared in this scope
     if (cmd != U_FLASH && cmd != U_FS)

did you have to edit this file **ArduinoOTA.cpp**?
thanks for helping me catch up and i will see if i have the same problems as yours.

tung256, 2019-11-03:
i used his "MQTT Only with WiFi Manager" bin file. no need to compile my own bin. works great! was able to go both direction. hope it works out for you

JoshuaGarrison27, 2019-11-05:
@tung256 I will give it a shot and see when I get a chance this week. That might be my problem.

Edit: Where did you find the precompile bin file? I only see the .ino files.

tung256, 2019-11-05:
the creator posted the bin file here : https://github.com/thehookup/Motorized_MQTT_Blinds/releases/tag/MQTT_WIFI
i followed the instruction and it works like a charm.  the bin file is on the bottom of that link.

JoshuaGarrison27, 2019-11-11:
@tung256 This still is causing mine to spin in one direction only for some reason.

tung256, 2019-11-12:
i bought all my stuff from the links he provided in the youtube vid.  the parts come in packs of 5. so i guess your next step is to try another component. try another motor, another controller, or another nodeMCU. mix and match, trial and error.
here's 1 of my blinds working https://www.youtube.com/watch?v=R5MM3VOXV_I
i will ramp it up to have 1 nodeMCU controlling 2 blinds in the living room. fingers crossed they work

JoshuaGarrison27, 2019-11-12:
I agree. I have several of each component. I'm going to try a few more.

thehookup, 2019-11-13:
I'm guessing your DIR pin is not getting a good connection, double check it.

JoshuaGarrison27, 2019-11-27:
I have not forgotten about this. I will try it as soon as I can. I have been working on Christmas LEDs from your videos @thehookup

Justind-hub, 2019-12-24:
@JoshuaGarrison27  I had the same issue, after a few very frustrating hours I accidentally disconnected the wire on D5 of the nodemcu. Works great now!

JoshuaGarrison27, 2019-12-24:
I just wrapped up my Christmas light project. I'm gonna try this again this week or next. I'll try your suggestion @Justind-hub thanks

Justind-hub, 2019-12-24:
@JoshuaGarrison27 Don't bother it stopped working a few minutes later. Also that's the "sleep" pin, at 12v the motor gets pretty hot pretty quickly without sleeping.

thehookup, 2019-12-24:
I would not recommend disconnecting the sleep pin.  Your motors will burn out with constant voltage supplied to them.  It's possible that the driver you are using sleeps on pin low instead of pin high.  Change the line

#define DRIVER_INVERTED_SLEEP     1
to
#define DRIVER_INVERTED_SLEEP     0

and report back.  Are you using the drivers that I specified in the readme? https://amzn.to/2OZqW1W

Justind-hub, 2019-12-24:
@thehookup Hey Rob!

I didn't realize it was the sleep pin when it came unplugged by accident and started working magically, when i picked up the motor a minute or two later I realized what I had done by how hot it was. Lol.

I used all of the exact parts from the links, and have tried swapping out each one to make sure it isn't a bad motor/driver.

The motor is sleeping correctly, I can spin it with my hands when it isn't "running", however I did try changing the line you mentioned with no success.
As of now it jerks back and fourth for a few seconds when I open or close the cover in HA. For a while it was only spinning in one direction (which would flip on each restart of the nodeMCU).

Justind-hub, 2019-12-24:
All I can think of is that the stepper arduino library has been updated with breaking changes since you originally wrote the code. I can understand what most of it is doing but definitely don't know enough arduino code to be able to try it with a different library

Justind-hub, 2019-12-28:
I got it to work! After looking at the wiring diagrams for the stepper motor and the pin out for the driver I started crossing wires between the motor and the driver. The attached modified schematic works great for me!
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

JoshuaGarrison27, 2020-02-05:
So we disassembled everything and then rebuilt and reprogrammed everything. Magically works again. So not sure what we did different this time around.

Closed 2020-02-14.

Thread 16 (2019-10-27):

Arduino IDE refuses to compile "Blinds_CONFIGURE.ino"

tung256, 2019-10-27:
this is my very first experience working with ESP8266 (i purchased using your affiliate link)

on Windows7, i use Arduino 1.8.10. In board manager, i have esp8266 by esp8266 community version 2.5.2. in Tools menu, i have:Tools -> Board -> NodeMCU 1.0 (ESP-12E Module)
Tools -> Flash Size -> 4M (3M SPIFFS)
Tools -> CPU Frequency -> 80 Mhz
Tools -> Upload Speed -> 921600
Tools-->Port--> com4

when compiling, i get this [error](https://drive.google.com/file/d/1-4yFY0elkVA2TDw5ZViSLAGbrf280FqB/view)

any idea what i did or did not do?

FILE> EXAMPLES> ESP8266> BLINK sketch works fine. i see my board's blue light on for 1 sec, off for 2 secs.
FILE> EXAMPLES> ESP8266WebServer>WebUpdate works fine too. i was able to visit its IP address

tung256, 2019-10-27:
i added more .cpp files   and not just the  .h files.
error messages decreased substantially from 160 to just 22. errors as seen [here](https://drive.google.com/open?id=1X1HGO1Qse-3qgOaGliUnJ2KhM2oygjAD)
what's next?

tung256, 2019-10-27:
C:\Program Files (x86)\Arduino\libraries\windows\ArduinoOTA.cpp:189:34: error: 'U_FS' was not declared in this scope

     if (cmd != U_FLASH && cmd != U_FS)

thehookup, 2019-11-13:
Looks like a bunch of libraries need to be installed, I'd recommend using the pre-compiled .bin file.

Closed 2019-11-13.

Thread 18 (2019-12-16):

esp8266 flashing blue LED light nonstop

tung256, 2019-12-16:
any idea what could be wrong when i plug the 12v adapter into my outlet and all  i see is the ESP8266 blinking blue LED nonstop every second?

JoshuaGarrison27, 2020-02-14:
@tung256 So... Im going to say you either have a bad ESP8266 board or the programming is wrong. Only reason I know this is because I fried 2 of my NodeMCU devices when I was rushing to plug everything back in. First try to reflash the software. If that does not work, then try another board if you can and check the wiring.

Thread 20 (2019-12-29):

Physical buttons

sajovicd, 2019-12-29:
Hello,

I found this very useful, but in some rooms like toalet I would like to have also buttons for close and open shades.
Is taht possible?
How do you solve the problem where you dont have your phone or tablet at the hand and want to close the shades?

JoshuaGarrison27, 2020-02-14:
It should be possible to wire up a momentary button that could do this. This is actually a really good idea since for most people you have to remove the twist rod mechanism.

virtualJonesie, 2020-05-22:
I'm working on this currently. I try to always have a non-phone, non-voice way to operate my smart devices. When I get this working, I'll post it here.

JoshuaGarrison27, 2020-05-22:
@virtualJonesie If you need someone to test, let me know. I just bought some momentary switches for this same issue.

virtualJonesie, 2020-05-22:
I bought some of these a while back. My goal is to make one sire open, and one side close. They're momentary, SPDT rocker switches, and they just so happen to fit in the factory hole for the tilt rod mechanism. No permanent modification of the blinds needed.

https://www.digikey.com/short/z4v1pv

My blinds are the 2" faux wood blinds form Home Depot.

https://www.homedepot.com/p/Home-Decorators-Collection-White-Cordless-Faux-Wood-Blind-with-2-in-Slats-10793478184453/206301010

virtualJonesie, 2020-05-23:
Here is my recreation of the original, with a SPDT rocker switch (linked above) included. I have not updated the code yet, but this should take care of the hardware side of things. Again, my plan is to use one side of the button for "open" and one side for closed, similar to the Home Assistant implementation created by The Hook Up.

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

virtualJonesie, 2020-05-24:
I made some very minor changes to the code. On button press, I have it publish either OPEN or CLOSE to the blindsCommand topic, depending on which button is pressed. Again, I'm using a SPDT momentary rocker switch, so one side is Open, one side is Closed. This way, the exisitng code handles the open/closing, and I don't have to check to see if the blinds are already in their desired state.

In the definitions section, I added definitions for the Button Pins
```
#define BUTTON_OPEN_PIN           D1
#define BUTTON_CLOSE_PIN          D2
```

In the setup() function, I set the modes to Input for those pins:
```
pinMode(BUTTON_OPEN_PIN, INPUT);
pinMode(BUTTON_CLOSE_PIN, INPUT);
```

And in the loop() function I added logic to react to button presses:
```
if (digitalRead(BUTTON_OPEN_PIN) == HIGH) {
    // Send a message to open the MQTT topic
    client.publish(USER_MQTT_CLIENT_NAME"/blindsCommand","OPEN");
}

if (digitalRead(BUTTON_CLOSE_PIN) == HIGH) {
    // Send a message to open the MQTT topic
    client.publish(USER_MQTT_CLIENT_NAME"/blindsCommand","CLOSE");
}
```

poggerb, 2020-07-04:
I wish I had found this earlier.....

I didn't have the coding knowledge, so improvised, by setting up some Sonoff Basics as the triggers for each of the blinds. Automation in HA to monitor the State and then Action Call Service to open/close covers.

I'll have to get some switches and try your modifications. Would have saved me some time money.... haha.

JoshuaGarrison27, 2021-01-12:
@poggerb You bought Sonoff Basics for each blinds installation? Wow. You were determined my friend. haha.

OOIOIOO, 2021-11-27:
Do not pull down low, most pins on NodeMCU are already pulled high. as such u set them as input, and that pulls them high by itself, so u send ground to your button and connect button output to that pin. in your code you check if the pin is Low ..... and .... bob is your uncle. there are no resistors involved, no power being sent anywhere and no sending 5v to nodemcu which runs on 3.3v.

Dannzig, 2022-01-17:
@virtualJonesie
I too love automation, but have a wife and 2 daughters that get frustrated and need manual controls. Did your solution work? Do you have any video of the buttons in action?

rixmix123, 2022-01-18:
If you have zwave set up you could program a button from aqara for example to control them.

Peterpc58, 2022-11-26:
>I also upgraded the software a lot with a web server and such, if i have extra time ill post it one day, but that's going to be in future.
When do you have the time to post your upgraded software?

JoshuaGarrison27, 2022-11-26:
> >I also upgraded the software a lot with a web server and such, if i have extra time ill post it one day, but that's going to be in future.
>
> When do you have the time to post your upgraded software?

My fork doesn't have physical button support but it has OTA built in. No Alexa support either. I just wanted to be able to update without taking down the blinds. So if that sounds okay to you here it is.... https://github.com/JoshuaGarrison27/Motorized_MQTT_Blinds

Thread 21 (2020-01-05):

Microstep pins configuration..

manojjenago, 2020-01-05:
Hi,

I can see the blow pins are used in code for microstep , but I guess there is no wiring to nodemcu.. Please let me know how we can define pins for microstepping or it is only a number ?? Sorry if it is basic. I am pretty new

#define STEPPER_MICROSTEP_1_PIN   14
#define STEPPER_MICROSTEP_2_PIN   12

Also, my motor runs forward 4-5times and backword again. It is moving forward and backward in the same time ...

Thanks,
Mj

echojjj, 2020-05-13:
My motor also goes forward and backward.

echojjj, 2020-05-16:
@manojjenago It's the motor wiring.  You have to find the two pairs.  One pair will be connected to A1 and A2 and the other pair will be connected to B1 and B2.  The wiring schematic included isn't correct for every motor.  This [https://user-images.githubusercontent.com/58923199/71539161-3fbe0780-28ed-11ea-80e9-8de35e4b15f4.jpg](url) @Justind-hub worked for me.

echojjj, 2020-05-16:
@manojjenago It's the motor wiring. You have to find the two pairs. One pair will be connected to A1 and A2 and the other pair will be connected to B1 and B2. The wiring schematic included isn't correct for every motor. This https://github.com/thehookup/Motorized_MQTT_Blinds/issues/15#issuecomment-569386423 @Justind-hub worked for me.

manojjenago, 2020-05-28:
After I changed to new motor and driver, it is working fine for me.
Thanks,
Manoj

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

Closed 2020-07-08.

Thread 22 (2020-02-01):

Gearbox

mssmison, 2020-02-01:
You mentioned you designed some gearboxes, do you have those stl's around by chance still for the 6mm rod? These steppers work fine on my smaller blinds, but the larger blinds require too much force to tilt for these to handle.

mssmison, 2020-02-02:
Ignore the above. I printed this  ( https://www.thingiverse.com/thing:3642542 )4:1 gearbox (I only needed I layer) along with a custom planet carrier which has the 6mm rod attachment and it worked great.

dwalto, 2020-02-25:
> Ignore the above. I printed this ( https://www.thingiverse.com/thing:3642542 )4:1 gearbox (I only needed I layer) along with a custom planet carrier which has the 6mm rod attachment and it worked great.

Do you have the stl for the custom rod attachment?  I have two larger blinds where the stepper alone can turn the rod.

mssmison, 2020-02-25:
> > Ignore the above. I printed this ( https://www.thingiverse.com/thing:3642542 )4:1 gearbox (I only needed I layer) along with a custom planet carrier which has the 6mm rod attachment and it worked great.
>
> Do you have the stl for the custom rod attachment? I have two larger blinds where the stepper alone can turn the rod.

Yeah for sure.

This was for my size rod which I think was 5mm. I found I still had to add a small bit of tape around the rod to get this to fit nice and tight. This is just the carrier, print the rest from the link above.
Also don't forget to increase your revolutions by 4x because of the 4:1 ratio.

[Planet_Carrier.zip](https://github.com/thehookup/Motorized_MQTT_Blinds/files/4248095/Planet_Carrier.zip)

Closed 2020-02-02.

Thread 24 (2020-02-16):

Hot motors, won't sleep

jtblunt, 2020-02-16:
I'm running 5 blinds inline as opposed to your setup with 3. Everything works fine and I have triple checked my wiring but it seems my motors do not sleep, when powered up the motors will not rotate freely and get very hot after a few minutes!

I'm using Alexa to control the blinds and I have also tried to comment out the line below in the file "Blinds_CONFIGURE_Portal_Alexa.ino":

#define DRIVER_INVERTED_SLEEP   1                   //Defines sleep while pin high.  If your motor will not rotate freely when on boot, comment this line out.

Is there anything I can do to fix this? or a way to test the sleep function is working?

jtblunt, 2020-02-17:
SOLVED With a bit of trial and error I think i've solved it. I moved the wire going from D5 - EN on the Node MCU (Green wire on your Schematic) on to the sleep pin on the Stepper Driver that I had soldered previously to the reset pin as discussed on your Video. All seem to work fine now! I've also setup a Routine within the Alexa app to auto open and close the blinds at a specific time every day.

Closed 2020-02-17.

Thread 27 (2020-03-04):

Safer motor

Alex1602, 2020-03-04:
Hi,

In the video you mentioned that the motor can get hot because of the overpowered driver. Did you find a good alternative that should work without tampering the motor? I think the fire insurance would have an issue with the current setup.

So question is, are there better motors out there that do not have this issue?

sukhvinder1, 2020-05-11:
@Alex1602 Hey Alex, were you able to solve this issue?

I was working on this project, everything works fine just the motor is getting super hot in 2-3 mins.

Any suggestions for me ?

Alex1602, 2020-05-12:
Unfortunately not, I did not start on this project until I get a better motor suggestion :)

sukhvinder1, 2020-05-12:
@Alex1602 Thanks for replying

@thehookup Can you please give suggestion to us ?

christensonautohome, 2020-05-31:
My blinds run for a max of 10 seconds. If you motor is running for 2 or 3 minutes then it’s wired wrong. If not in use then there is no power draw and the motor is room temperature.

thehookup, 2020-07-08:
There is no fire issue with this motor if you have it installed correctly.  I've run this motor for over a minute continuously at 12V and it doesn't get too hot to touch.  The only problem would be if you haven't wired the enable pin correctly.

Closed 2020-07-08.

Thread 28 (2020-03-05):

Questions from a n00b - First Arduino/NodeMCU project

k0bayash1maru, 2020-03-05:
This is my first ever DIY with a Arduino/NodeMCU.

I have a few questions on the project, I am a complete n00b so please excuse any lame questions :)

**Prereqs**:
```
1. I've bought all the parts from the links you posted with crimper set and a soldering kit
2. Watched your videos on Arduino and Home Assistant/Node-RED  and of-course the one on the blinds multiple times
3. Installing Arduino and Home Assistant and Mosquito broker on my always on Ubuntu server
4. Have the 3D parts printed
5. Have a few CAT 5 cables lying around
6. Have an Alexa device, Alexa app on an iPhone
```

**Question**:
1. I looked at the wiring diagram you added but this is still very confusing to me. I plan on doing this project for the 3 blinds in my bedroom like your setup with 3 motors going to a single NodeMCU:
```
1a. You said you connected the wires from each blinds together before attaching them to the NodeMCU - how did you do that ?
1b. What does the wiring for one motor + one NoedMCU look like ?
1c. What is the wiring when you attach them together ?
1d. How is power hooked up to these ?
1e. What are the clear cases with the orange tabs that you connect these ? (where can I buy them ?)
1f. You said "need to make sure that the connector is in the right orientation" - What does this mean ?
```
Can you please send some pictures of the above wiring I think that will help me a lot!

2. I plan on using this with Alexa:
```
2a. Do I just upload the  Blinds_CONFIGURE_Portal_Alexa.ino via Arduino to NodeMCU (after making the config changes) or do I need to do anything with the .bin file ( I assume its an either or)
2b. Do I need to upload Blinds_CONFIGURE.ino ? I assume I use this  along with Blinds_CONFIGURE_Portal_Alexa.ino and this will control the blinds via home assistant.
2c. I assume I don't need Node-RED for this - is that right ?
```
`3. Upload the HomeAssistant config with the YAML file`
`4. Anything else that I need to look for from an absolute beginner's prospective ?`

Any help greatly appreciated!!!

Thanks in advance

ImpossibleCodes, 2021-04-04:
I'm wondering the same thing, I wired it up using the schematic on a breadboard and ended up emitting magic smoke, If you or someone else has figured it out and has pictures or something to help, that would be amazing

k0bayash1maru, 2021-04-04:
Try this schismatic:
https://github.com/thehookup/Motorized_MQTT_Blinds/issues/15#issuecomment-569386423

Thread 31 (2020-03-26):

Motor Keep shifting position 2 or 3° Anti CW in each cycle.

vinodnx, 2020-03-26:
Hello All,
Motor Keep increasing position 2 or 3° Anti-CW and decreasing 2 to 3° CW in each cycle. Please suggest any recommendations.

Please refer below video for more details

https://www.youtube.com/watch?v=lweSv-2Ar-U&feature=youtu.be

poggerb, 2020-07-04:
Vinodnx, could it be due to the motor sometimes missing steps?

This article suggests driver current settings can cause missing steps.

https://www.makerguides.com/drv8825-stepper-motor-driver-arduino-tutorial/

thehookup, 2020-07-08:
Which version of the code are you using vinodnx?

vinodnx, 2020-07-08:
Hello Friend,

I was using a servo motor, which is not the same as your stepper motor.
sorry to bother you

Regards
Vinod

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

Closed 2020-07-12.

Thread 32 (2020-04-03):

My nodemcu won't connect to my MQTT server running on my VM

furlough1, 2020-04-03:
NodeMCU won't connect to MQTT:  Attempting MQTT connection...failed, rc=2 try again in 5 seconds. In the "Open serial monitor" I don't see a port for the MQTT server. How do I add a port or reset the NodeMCU?

thehookup, 2020-07-08:
Connect pin D1 to ground to reset your settings and return to the WiFi portal.

Closed 2020-07-08.

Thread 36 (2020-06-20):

SCAD File for BlindsBase

dsandor, 2020-06-20:
It would be very helpful to have access to the OpenSCAD file for the `BlindsBase.stl` file. It would be useful for minor variations in blinds. For example by blinds need about 8mm trimmed off the top of the assembly.

p-doyle, 2020-06-29:
Yes, please!  Current design doesn't work with my blinds either and I was hoping not to have to design it from scratch.

dsandor, 2020-06-30:
I created one on my own. Mounted it in 2 blinds and it seems to work great. I had to put a tiny bolt through the metal to act as a backstop. The motor would work its way back and detach after about 20 cycles. The bolt was a super simple way to prevent that. I suppose you could make it wider to be a tight fit but this worked well for me.

https://gist.github.com/dsandor/c1f7e3ffebb0b491225a713f0423aede

Enjoy.

thehookup, 2020-07-08:
Thanks dsandor, added your SCAD file to the file list.

Closed 2020-07-08.

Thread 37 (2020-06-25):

Fault Pin Connected to 5v?

ryancasler, 2020-06-25:
I am wondering why you have the DRV8825's Fault pin connected to 5v.  From what I can see from other schematics that use this driver, that pin is never connected to the VCC of the microcontroller.  The datasheet says that it is output low when there is a fault detected.  Why would you want to short out the power supply if there is a fault detected?  Won't that burn out your supply?

echojjj, 2020-07-01:
I was wondering the same thing.  I think the DRV8825 GND is to common to the microcontroller ground, and that be the mistake in the wiring diagram, but it does work even with 5v to fault pin.

ryancasler, 2020-07-03:
And doesn't without the 5v to the fault pin.  I am wondering if it has something to do with using the Enable pin rather than the sleep pin to power down the motor controller when not moving.  I decided to just try it since I have 5 of each and only 3 windows where I'd possibly use them.  So, even if I blew one, I'd still have one as a backup.  :)  Glad I wasn't the only one that was confused by that.

thehookup, 2020-07-08:
That is really strange.  The reason I wired it that way is that I'm used to working with A4988 drivers that take Vdd on that pin.  I've always heard/read that the DRV8825 can be wired interchangeably with the A4988, so that's what I did.  It hasn't caused any issues for me.  It looks like the only other pin to use to supply Vdd is the RST pin?  That's strange to me.

ryancasler, 2020-07-08:
Yeah, it is definitely required to have the pin connected to 5v to get it to work.  I just can't figure out why either.  I it must have something to do with using the EN pin instead of the SLEEP pin to shut the board down.

When it comes to the tiny current adjustment on the board, when you said in the 12 o'clock position, what did you mean?  when oriented in which way?  Did you mean half way between min and max?  I have only 3 blinds to automate and 5 motors but I'd rather save them for other screwups later on than to blow one up unnecessarily.

echojjj, 2020-07-08:
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
[https://www.pololu.com/product/2132](url)

echojjj, 2020-07-08:
@ryancasler the position of the pot would be at 12:00 when the flat edge is at 6:00.  look closely for the flat edge.

echojjj, 2020-07-08:
@ryancasler the pot is at 12:00 when the flat edge is at 6:00.  look closely for the flat edge.  here's a picture of a pot at 12:00
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

softtechs1, 2022-07-18:
I got everything wired per the diagram, programed MCU and getting data from MQTT. Just can't get the motor the move at all. Does the GND on the DRV8825 need to be connected to the GND of the MCU? From looking at the wiring on the A4988 driver, its connected to the microcontroller.

ryancasler, 2022-07-20:
How are you powering the board?  Are you using a buck converter like in the diagram or are you using a 12v supply and a 5v supply.  I have mine wired like the pic and it works.  You just have to make sure the two grounds are tied together somewhere.  No ground, no current flow.

softtechs1, 2022-07-20:
Thanks so much for responding! I purchased everything from the amazon links and wired as in the pic schematic. Using the 12v power supply, connected to the input side of the buck converter. Ran another 12v wire pair to connect the DRV8825’s UMOT/GRN pins. NodeMCU 12E gets power from the buck’s 6V output side. From the buck converter output side, I also have another 6V pair, which only the + from the buck converter is connected to the DRV8825 FLT pin, the negative is not connected as per the schematic, which is confusing. Everything else the schematic should be straight forward (Step, Dir, EN and 4 Motor wires). From what’s in the schematic, I don’t understand how the grounds tie together?
See my test bench photos.

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

ryancasler, 2022-08-01:
First of all, the output of the buck converter should be set to 5v.  Not 6.
Second, how do you have the wires coming out of the Buck converter.  one side is + and the other is -.  So you need one from each side to the board.  You have two of the wires for the motor backwards.   The orange and pink should be pink-orange.
What type of 12v power supply are you using?  How many amps does it put out? Have you adjusted the current limiter on the DRV?  If that is all the way down, your motors won't move.
If you disconnect the buck converter's + line and just keep the gnd attached, you can plug in your board to your PC and see the output of the Serial log so you can try and see what is happening.  That way you can tell if it is able to connect to your wifi and actually receive the MQTT message.

softtechs1, 2022-08-01:
@ryancasler I got this all working by replacing a bad DRV8825. Seems I received a bad batch along with motors. Installed 2 blinds so far and working on the 3 more. Thanks!

Closed 2020-07-08.

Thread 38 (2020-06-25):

Cannot Compile ST Sketch

ryancasler, 2020-06-25:
The Sketch Uploaded for ST will not compile as written.  Right off the bat it gives an error that the IP is formatted incorrectly at the top of the sketch.  There are too many decimal places because it is treating it like a number.  How did you ever get this to compile?

ryancasler, 2020-06-26:
After many modifications I was able to get the sketch to compile and connect to ST.  I get all my motor components on Monday.  If everything works, I'll send a PR to update to a working version.  I should also have a DTH/ Hubitat driver as well.  I have one working in dry run with no motor attached.  So, if wiring is as easy as you say, should just be able to plug it in.  Fingers crossed!!

Fran6u, 2021-06-16:
Hi. I am new at coding and HA and facing similar issues, can you possibly post a sample of the modifications you made.

Fran6u, 2021-06-16:
> After many modifications I was able to get the sketch to compile and connect to ST. I get all my motor components on Monday. If everything works, I'll send a PR to update to a working version. I should also have a DTH/ Hubitat driver as well. I have one working in dry run with no motor attached. So, if wiring is as easy as you say, should just be able to plug it in. Fingers crossed!!

Hi. I am new at coding and HA and facing similar issues, can you possibly post a sample of the modifications you made.

Closed 2020-06-26.

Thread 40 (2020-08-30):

Integer Position

ledrewski3, 2020-08-30:
I'm having trouble running the motor for the first time. It won't move. Not sure if I'm sending the topic the right way?

millerj1119, 2021-03-02:
I am having this same problem.  I have all of the connection correct and flashed my 8266 with the needed information.  Downloaded the MQTT Explorer and everything seems to be sending and receiving correctly. but no motor movement.  Any ideas?

kboghdady, 2021-11-29:
I am having the same issue

T00LF00L, 2022-06-15:
A bit late here, but I just built this project and had the same problem. I can tell you what’s wrong, the wiring diagram is incorrect. Wire the stepper drivers this way and it will work.
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

webxl, 2022-07-23:
This did the trick for me, thanks!

T00LF00L, 2022-07-23:
@webxl Awesome, glad I could help someone! I’ve since done a little more research and learned this driver was updated at one point and the pin out changed. The driver pictured in the wiring diagram is the new version, but the wiring as shown is in fact correct for the old driver version.

reinervl, 2022-08-17:
@T00LF00L this new wiring diagram fixed it for me as well., so thank you! However, I may have a new issue. Every time the nodeMCU loses power and restarts after power is back, the motors won't move until I unplug them and plug them back in. It's as if the nodeMCU can't handle the motors being connected at start-up. Any ideas on how to remediate this?

reinervl, 2022-08-26:
@T00LF00L thanks for your help. I should also mention that I have 4 stepper motors and drivers (1 driver per motor) connected to one nodeMCU. When I leave them all connected and I plug in power, all 3 pins (EN, STEP, DIR) read 1.54V so floating? When I disconnect all motors/drivers and then plug in power everything works and STEP and DIR read low (0V) and EN reads HIGH (3.3V).

T00LF00L, 2022-09-02:
@reinervl To be perfectly honest with you.. this is the first circuit I've built in 30 years, the last time I wrote code was on a Commodore 64 and this project took me 4 days of troubleshooting to finally get working with Home Assistant and HomeKit.  Coincidentally I just had one blind do the exact same thing you described, but it's only happened that one time.  I did some Google.. it says these three pins have a 'weak' high during boot, but they can be high or low and it won't affect boot.  So the only other thing I could find is maybe it's a power delivery issue during boot?  Sorry I can't really be much more help as electronics were very different in the 80s, you may want to open a new discussion? I'm still trying to figure out why mine occasionally open back back up at night..

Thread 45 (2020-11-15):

Are 28BYJ-48 motors strong enough?

nuaimat, 2020-11-15:
Hello and thanks for the amazing detailed video, I truly appreciate the effort you put into this,

After buying the items and following exactly your instructions, I'm facing this problem, seems like the 28BYJ-48 motors are not strong enough for my blinds https://youtu.be/iennyIrTf10 truth is, I tried the same setup on another small window blinds like 1/3 the size of these in my video, and they have the same problem, any idea what might have gone wrong, or do you have a recommendation for a stronger motor?

PS: one thing I was suspecting I might have done wrong was converting the 28BYJ-48 from unipolar to bipolar. but I build a small circuit with LED and get sure that the common wire (red) was disconnected so I am sure that was not the issue.

Thanks

JoshuaGarrison27, 2021-01-12:
@nuaimat I cannot speak for your issue directly. But it works perfectly fine for my blinds. Are your blinds more "premium" with actual wood (or fake wood) slats? If so, it could very well be a weight/torque issue. However, it looks like in the video that you are getting some movement, so I wonder if it has something to do with some kind of slipping with however you mounted your 3d printed adapter. Maybe a video of the inside while it is trying to open would help diagnose it?

Here is what I can tell you with certainty...I have the 28BYJ-48 motors and they work great for my blinds.

nuaimat, 2021-01-12:
@JoshuaGarrison27 Hey Joshua, thanks for your input, it's totally a great idea, I think I should put a small camera in there and report back.
I gave up on 28BYJ-48 right after this issue was opened, I tried using Nema17 with Tasmota but still having similar issues.

Whogives23, 2021-01-12:
@JoshuaGarrison27 . Ensure you have the polarity of both coils wired correctly. Otherwise they would counteract each other.

I have a similar(if not larger) being driven by two 28BYJ-48 motors.
https://photos.app.goo.gl/2onbQ6M7vUqVC6Wh8

xdenneboom, 2021-02-05:
Were you able to figure out the issue? I have the exact same thing happening, and was wondering if the motor was strong enough too. After a few milimeters of movements, I get the exact same sound without any movement, just like yours.

My blinds are similar in width, but extend all the way to the floor. It does seem others have bigger or similarly sized blinds working effortless.

I have controlled the motor without hooking it up to the blinds, and seen the rotation happening without those sounds and issues. So it's definitely something that only happens when attached to the blinds.

OOIOIOO, 2021-11-27:
@Whogives23

is there a reason you are using the "non converted" motor and the controller it comes with?  Also do u have an issue with overheating? I got an impression motor was heating up like crazy when on that controller

Dannzig, 2022-01-17:
> @JoshuaGarrison27 . Ensure you have the polarity of both coils wired correctly. Otherwise they would counteract each other.
>
> I have a similar(if not larger) being driven by two 28BYJ-48 motors. https://photos.app.goo.gl/2onbQ6M7vUqVC6Wh8

What is that Manual button you are using yo open and close them?

JoshuaGarrison27, 2022-01-18:
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

I actually abandoned the idea of having a manual button. I was running out of time on my vacation to install and everything. 😂

petereit, 2022-04-25:
On my first activation, I had the exact same problem. Two things helped:

1. While I had the blinds down, I put some lithium grease on every round plastic bushing that snaps the rod into place and worked it back and forth until rotating the rod became almost effortless.
2. I made sure the very bottom of the blinds was resting on a firm surface (my blinds are mounted inside the window casing, so the bottom rests on the window stool) so there was just a bit of slack on the lines so that the motor doesn't have to strain against the entire weight of the blinds.

dmasters74, 2023-07-28:
Hi

Can anyone recommend a replacement motor with a more holding torque. My blinds fully close with this motor but the weight of the blinds pulls the motor back open causing the blinds to open slightly.

petereit, 2023-07-28:
Ideally, your blinds should be secured at the bottom so there’s no weight pulling on either side.

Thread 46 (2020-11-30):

Blinds_CONFIGURE:1:83: fatal error: SimpleTimer.h

jrsmith77, 2020-11-30:
I'm getting this error when trying to verify/compile the sketch. I'm very new to this altogether, so bare with me.
  I have tried pointing to different URLS, and also attempted to download the files locally and point to them. Still no luck. Anyone else experience this and know how to resolve?

Arduino: 1.8.13 (Windows 10), Board: "NodeMCU 1.0 (ESP-12E Module), 80 MHz, Flash, Legacy (new can return nullptr), All SSL ciphers (most compatible), 4MB (FS:2MB OTA:~1019KB), 2, v2 Lower Memory, Disabled, None, Only Sketch, 57600"

Blinds_CONFIGURE:1:83: fatal error: SimpleTimer.h: No such file or directory

 #include <SimpleTimer.h>    //https://github.com/vigneshankar/Simple-Timer-Library

                                                                                   ^

compilation terminated.

exit status 1

SimpleTimer.h: No such file or directory

This report would have more information with
"Show verbose output during compilation"
option enabled in File -> Preferences.

jrsmith77, 2020-12-01:
Issue was ignorance on my part.

richcoliver, 2022-02-26:
My ignorance too but what was the fix please ?

Closed 2020-12-01.

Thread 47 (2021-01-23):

Connecting to MQTT broker, but MQTT broker doesn't see it

yetihahn, 2021-01-23:
I love this project. I have watched the video about 6 times. Read and re-read the directions. However, I still can't seem to get my MQTT broker to see the ESP.

I flash the ESP (using tasmotizer) with the .bin file, and enter all the details, the ESP connects to the broker (as seen in the monitor via Arduino IDE). However, in HA I cannot see the ESP. I'm looking in configuration>instances>MQTT>"10 devices"
My other MQTT devices are there. But not the ESP. 🤔
My MQTT experience is limited Tasmota using MQTT with "setoption19 1" and it then appearing in HA right after.

Troubleshoot I have tried:
Flashing the .bin via tasmotizer (making sure to erase content on the ESP)
Using the Arduino IDE to upload the sketch to the ESP
Trying 3 ESP8266s (two 12-E and a Wemos D1 mini)
Flashing the Alexa .bin to see if Alexa can find it. No luck.
Using the other Alexa .bin. Still no luck. Left it connected over night to see if it "magically" gets found. (has happened with other projects.)
Leaving the ESP flashed with MQTT version powered overnight to see if it "magically" gets found by MQTT.
Using Fing and my router's app to ensure the ESP is on the network and has an IP address.
Putting in the wrong details for MQTT to see if the ESP still reports connecting to the broker. It doesn't claim to connect to the broker with the wrong IP, or password, or username. So I know it's not claiming to connect by default.
Also I've made sure "enable newly added entities" is turned on. I've toggled it off and on again to see if that "shocked" it into finding the ESP.

I'm guessing there's a way to have my broker find the ESP. But, despite hours of googling, I can't figure it out. 😞 if anyone could point me to a "MQTT for dummies" (I've watched Rob's, but wasn't able to find what I needed) or point out the flaw in my methods I'd really appreciate it.

yetihahn, 2021-01-23:
Also I've made sure "enable newly added entities" is turned on.
I've toggled it off and on again to see if that "shocked" it into finding the ESP.

xHirscHx, 2021-01-25:
I only was  able to get the ALEXA  bin to work.  I was able to go threw alexa to smarthings then to hassio with a simulated blinds setup. I dropped that setup and now running tasmota  blinds and anther 2  blinds running on esphome threw hassio. Hours of trying to get a moter (use tasmota) or stepper moter( use esphome) to wotk.

xHirscHx, 2021-01-27:
Save your self of hours of Google time( trust me)  the hookup blinds work great with alexa but i needed local. look at this -----https://tasmota.github.io/docs/Blinds-and-Shutters/  same setup you already have and im guessing you already have tasmota devises.

yetihahn, 2021-01-27:
This looks good, I'll have to dig into this! I like the idea of using Tasmota as I'm already familiar with it. And yes, I've been Googling for hours...

I ended up figuring it out. I'll post what worked in case someone else needs this in the future.

With the Alexa files I had to reboot the Echo and ESP8266 to get it to work. (Had some help.) I also waited over night between setting up and rebooting, which may have helped?

With the MQTT files I ended up downloading MQTT Explorer to understand what's happening with MQTT. This helped me see the states of devices and messages as they were sent (kinda.) It also let me publish and see how it changes things on the network. This took some trial and error, and caused me to learn a lot.
When going into HA>Configuration>Integrations>MQTT># devices I still don't see my window blinds. I'm guessing this is due to the integration only showing MQTT devices that have states published to topics. The file Rob wrote doesn't do that, so I was confused why the window blinds weren't appearing in HA. Looking with MQTT Explorer and seeing the motor blinds listed there caused things to click for me.
After adding the Cover (provided by Rob) in File Editor>configurations.ymwl I was able to publish positions to the device/topic by going to HA>Configuration>Integrations>MQTT>configure>publish a packet. For topic I can put:
*nameOfMQTTDevice*/positionCommand
For payload I put "1" then clicked "publish" then put "12" as the payload and clicked "publish" again. This got the motor to move. (Rob explained that their first value sent is the "home" position, so that part wasn't confusing, but mighy be over looked by others.) Learning to publish with MQTT was the tricky part for me. I practiced publishing using MQTT Explorer while seeing the states change and messages being sent, and was able to get the hang of how MQTT works. I'm very visual so not seeing states in HA really threw me off.

Hopefully this helps other in the future!

Closed 2021-01-27.

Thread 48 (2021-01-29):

NodeMCU USB port missing in IDE

xdenneboom, 2021-01-29:
I have never used NodeMCU before. I have used Arduino in the past, so I'm not completely new to this. However, for this specific board my macbook doesn't seem to recognize the usb port. When I connect my arduino, the USB port shows up. It doesn't for the NodeMCU. Upon connection, the board blinks a blue light 2times though. I can't get board info or write to it.

This seems to be a known issue for NodeMCU, and there are a couple of drivers available that I need to install. I've tried each of them, without much luck. I'm pretty sure, I keep installing random wrong drivers.

Could any of you point me to the correct driver I would need on macOS Catalina with the board that is recommended in this project? That's the one I purchased.

So far, I have installed and failed with these two drivers:
- CP210x usb-uart
- CH43x from a chinese manufacturer website

xdenneboom, 2021-01-30:
Ok. after switching to a third different usb cable, it got resovled. Wasted 2days on this. Issue can be closed :)

Closed 2021-01-30.

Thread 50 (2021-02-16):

Motor Temperature

CalgaryCM, 2021-02-16:
Hey, Can anyone confirm if the motor gets HOT if the NodeMCU/ESP8266 is not connected?

I am starting this amazing build and during voltage checks I notice that the motor gets very hot when the nodeMCU/esp8266 is not connected. My initial gut feel (and prob incorrect as I am just starting) is the nodeMCU using the enable pin to sleep the motor. My concern here is if something were to happen to the nodeMCU it would stop sending "sleep" to the motor and the motor would heat up to the point of it being a fire hazard.

I did verify my wire connections several times. I assume the wire color code on the diagram matches the wires on the motor and I have them connected properly.

TIA!

Smitty357, 2021-03-18:
Mine does as well. I have tried multiple things with the same results.
I have had mine in use for several months working great, but decided to modify it because it seems to have connection issues at times. During this testing is when I found it gets extremely hot. I thought the enabled pin would have turned off when not used. Maybe the board is waiting for some feedback on the position to know it is complete?

OOIOIOO, 2021-11-27:
I'm still in the process of working on this project, but I had an episode where I killed node mcu and the controller by shorting probably and didn't realized that and put the blind up. After an hour or so I realized that the blind doesn't work very well so I took it down. It turns out it was soo hot that it melted the adaptor.

So my advise to anyone who is doing this is double sleep the motor through the Fault pin, by connecting it to one of the pins on nodemcu(instead of 5v directly), then setting the pin to High when needed and to Low otherwise, this way controller is completely off, and u don't have a risk burning your house. :)

rixmix123, 2021-11-27:
Can you provide a diagram of that double sleep set up? Everything for me works perfect, but I did disconnect the node mcu to test and the motor started to heat up. Thanks!

rixmix123, 2021-11-27:
> Can you provide a diagram of that double sleep set up? Everything for me works perfect, but I did disconnect the node mcu to test and the motor started to heat up. Thanks!

@thehookup any ideas for a good fail safe of the node does fail eventually?

OOIOIOO, 2021-11-27:
@rixmix123
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
its fairly simple really, note the Orange line from D8. Its mostly software, the way I did it, I set it as output and during setup I set it to LOW, than any time I run the motor I set it to HIGH, and in the part where the moving is set to false, I set the pin back to LOW. So Controller is essentially always off and never heats up.
Now technically gpio pins 1 to 15 I think are all pulled HIGH so there is a chance that during boot the controller will on until the code kicks in, I believe gpio 16 is defaulted to LOW, so u could try that to be extra safe.

OOIOIOO, 2021-11-27:
> @rixmix123 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 its fairly simple really, note the Orange line from D8. Its mostly software, the way I did it, I set it as output and during setup I set it to LOW, than any time I run the motor I set it to HIGH, and in the part where the moving is set to false, I set the pin back to LOW. So Controller is essentially always off and never heats up. Now technically gpio pins 1 to 15 I think are all pulled HIGH so there is a chance that during boot the controller will on until the code kicks in, I believe gpio 16 is defaulted to LOW, so u could try that to be extra safe.

actually I just checked some resources and they say the D8(got lucky there :)) is being pulled LOW standard, so u good to use that, as GPIO 16 is one of them weird ones, that polly noone should use.

rixmix123, 2021-11-27:
@OOIOIOO Thanks so much! Forgive me for being a noob as this is my first project working with the node mcu's and the programming of them. But do I need to modify any code with your set up?

rixmix123, 2021-11-27:
@OOIOIOO and one more question just to be clear, this set up would prevent the motor from heating up if the node MCU failed or was disconnected? Thanks again!

OOIOIOO, 2021-11-27:
> @OOIOIOO Thanks so much! Forgive me for being a noob as this is my first project working with the node mcu's and the programming of them. But do I need to modify any code with your set up?

yes in a few places where i described aboe, due to where this stuff is , it will be hard to point u exactly, as i dont know what you have. i will eventually do a pull request with my changes but im not done yet. :)

rixmix123, 2021-11-27:
Thanks again! I'll be on the lookout!

OOIOIOO, 2021-11-27:
> @OOIOIOO and one more question just to be clear, this set up would prevent the motor from heating up if the node MCU failed or was disconnected? Thanks again!

if mcu is disconnected, yes, if it failed .... hopefully, its electronics and you are playing with it, so nothing is for sure, but its better ... to the best of my knowledge. I tested it on my failed items as well and it saved it fixed it there :)

tkffaul, 2022-02-17:
@OOIOIOO just wanted to tell you how awesome of an idea this was. I modified the program and wiring like you showed and it works great! I like not having the driver powered up when the blind isnt doing anything, just made a lot of sense! I really think you should push this up as a pull request and have them modify to project!

rixmix123, 2022-02-17:
How do you modify the software? Do you make changes in Arduino code? I have the blinds up and running and connected to Wemo plugs that turn off when not in use, but I'd love another fail safe just in case! 😀

tkffaul, 2022-02-18:
Yes you have to modify the programming in Arduino... Here is how I did it... and I'm no expert, but it works...

**At the top under the var define section:**
#define STEPPER_MICROSTEP_2_PIN   12
#define STEPPER_POWER                    D8  <-- Add this Line

**At the bottom in the setup subroutine:**
void setup() {
  pinMode(STEPPER_POWER, OUTPUT);     <-- Add this Line

**Under processStepper Routine:**
  if (newPosition > currentPosition)
  {
    digitalWrite(STEPPER_POWER, HIGH);   <-- Add this line
    _Other stuff_

  if (newPosition < currentPosition)
  {
    digitalWrite(STEPPER_POWER, HIGH); <-- Add this line
    _Other stuff_

  if (newPosition == currentPosition && moving == true)
  {
    #if DRIVER_INVERTED_SLEEP == 1
    shadeStepper.sleepOFF();
    #endif
    #if DRIVER_INVERTED_SLEEP == 0
    shadeStepper.sleepON();
    #endif
    digitalWrite(STEPPER_POWER, LOW);    <-- Add this Line
    _Other Stuff_

This defines STEPPER_POWER as D8 and then activates D8 as an output pin. We then flip it on before a move and shut it down when it reaches its location. Seemed simple enough, and the motor never gets warm.

rixmix123, 2022-02-18:
Awesome! Any chance you can post all the code for reference? I'll try it out!!!

petereit, 2022-05-19:
Curious, did you cut the center trace on the motor's internal PCB as Rob instructed? I was testing adding a second motor in parallel for a very large blind. I forgot to cut that center trace and it got VERY hot. The other motor I was testing had the center trace cut and always remained cool to the touch.

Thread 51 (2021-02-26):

Raspberry Pi breadboard control works, but motor spins constantly when installed over longer wires

SummittDweller, 2021-02-26:
Great project, and I have it working in Alexa mode as-written.  However, for adjustment purposes I'd like to be able to swap the ESP8266 controller with a RPi 3B+ that I've programmed in Python.  The odd thing is that this works when I make the connections with the DRV8825 mounted in a breadboard using short Dupont connectors to make the circuits.  However, when I connect the same circuits using a long CAT5 cable in place of short Dupont connectors, the motor runs without control.  I've continuity tested each CAT5 wires individually and found no problems.

In both cases I'm pulling 5v from the RPi and using GPIO pins 16, 20, and 21 for ENABLE, DIR and STEP, respectively.

I was going to prepare a diagram, but since it's not yet working in "production" I haven't created one.   Can anyone suggest what might be wrong?

SummittDweller, 2021-02-26:
Just FYI... since posting here I've switched my wiring so that the DRV8825 is mounted near my power source and RPi, only the 4 motor output wires are of any length.  In fact, I'm using a standard CAT5 cable with each twisted pair carrying one of the 4 outputs.  My test cable is 20' in length and seem to have reliable control over the motor with no ill-effects, at least not yet.

I may just stick with this configuration since it is simple to wire, but am still curious why long wires from the RPi to the DRV8825 were causing apparent problems.

At least now I have reason to put together that diagram I promised, and I'll add it to this issue once I have.

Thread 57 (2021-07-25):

Multiple Motors and 1 MCU Wiring ?

jeffdadamo, 2021-07-25:
I’m trying to recreate exactly what you’ve done in the video, but I have no clue how to structure the wiring for 3 stepper motors and connect them all to one MCU. Do you have a wiring schematic diagram that shows all three motors wired up?

hdubel94, 2021-07-26:
If you want all three blinds to act as one component, you should wire them in parallel off the same output. Pardon the potato image, I drafted it up quickly.

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

I highlighted the connection nodes in red. Whether there are 2 nodes or n nodes, they can all be combined into one theoretical node when in parallel. Think of a hub and spoke where the node is the hub and the drivers & motors are the spokes of the wheel.

I actually have 3 of these blinds running as "one" blind. As long as they all come off of the same NodeMCU outputs, they should be fine. Each wire from the output needs to go to a respective motor driver.

If you need anything clarified or have more questions please let me know and I'll try to be of help.

jeffdadamo, 2021-07-27:
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

So here’s a diagram I drew up based on your comments. Is this how you’d do it? Sorry for the colors, I didn’t have much to work with!

Basically only one cat 5 coming from the Power/Buck/MCU that gets spliced to feed each of the Stepper Drivers.

hdubel94, 2021-07-27:
Yes, your diagram looks correct to me. Sorry I didn't have the time to make a more detailed one.

Your drawn solution is exactly what I have done with mine. One cat cable from the signal source (Power/Buck/MCU) that runs to each motor driver and is spliced exactly as you said/drawn.

I actually bought off Amazon a white, flat cat 6 cable and was able to feed it beneath the floor trim around the room. Not sure I'd recommend working with the flat cables unless you're very comfortable working with small wires. They were a bit of a pain to strip for the DuPont connectors.

Hope this helps and looking forward to your finished implementation!

jeffdadamo, 2021-07-27:
Awesome, thank you! Now I just need to order all the parts!

Closed 2021-07-27.

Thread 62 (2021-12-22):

Motor spazzing out when sending up/down commands

jeffdadamo1, 2021-12-22:
Hey everyone, finally got around to working on this project. I've gotten one all wired up to test before I put all three motors in line for my end setup.

However, with just the one wired up according to the wiring diagram, when I push "up" or "down" in HA, the motor "shakes" or moves a little in one direction, then back the other. The movements seem to be entirely random.

I've double and triple checked the wiring setup and I can confirm that I've done everything exactly as described. Any ideas as to what might be going on here?

Thanks!

dogtreatfairy, 2022-01-24:
I just had this problem yesterday after scratching off the middle trace he tells you to scratch through. Try re-bridging that connection. I ended up not scratching through that trace on all of my blinds and it fixed the problem.

jeffdadamo1, 2022-01-24:
Okay, I can give that a try. I thought that was required to turn it into the type of motor we wanted/needed for this application and the code we have ? Does this mess anything else up from a power perspective ?

jeffdadamo1, 2022-01-24:
This is amazing news. I've got everything else ready to go for this project (custom printed holders for my blinds, the wiring, everything) except for this darn issue. I'll try this out and see how it goes. Thanks for the response!

Closed 2022-01-24.

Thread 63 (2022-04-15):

PCB Walkthrough?

petereit, 2022-04-15:
I have 4 blinds in my sunroom that I'd love to automate using Dave Morris's Quad Blind PCBs. The Blind Controller and Blind Motor boards make sense to me, but I'm not sure how the third PCB, the "Main Power From Supplies" board fits into the project.

Can someone give me a rundown, a diagram or a link to his project page?

rustypasini, 2022-07-13:
Did you ever get a response to your question?

petereit, 2022-07-14:
No. I just started with Rob‘s controller PCB layout, added two RJ45 connectors and ran 4 flat CAT6E cables to 4 motor controller boards. All 4 of my blinds are working great!

furlough1, 2022-07-14:
No, I didn’t

Sent from Mail<https://go.microsoft.com/fwlink/?LinkId=550986> for Windows

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

Closed 2022-05-15.

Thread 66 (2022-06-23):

Motor (Jaggedly?) Turns Same Way Unless Force Applied

BzowK, 2022-06-23:
Hey All -

Had most parts sitting around and wasn't happy with current solution so gave it a shot.  Only main differences was that instead of using a buck converter (couldn't find one), I used a step up converter to step the 5V to 12V plus am using a Wemos D1 Mini instead of ESP8266.  Built it, connects with MQTT, and can control with HA.  Unfortunately, am having an issue...

**Issue**
Triggering OPEN or CLOSE moves the motor in the same direction in short bursts.  It doesn't have much torque and applying pressure to the motor while turning makes it reverse direction oddly enough.

**What I've Tried**
- Verifying wiring
- Re-bridging the 5V trace I cut on the motor's PCB (No change)
- Routing 5V to the two connected pins on the driver PCB

5V source is 2.4A and step up converter can pass 2A so would think power isn't issue but may try digging up 12V adapter and testing with it directly to driver PCB.

Any suggestions?  Thanks

reinervl, 2022-08-06:
I had the same happen to me until I realized I fried one of the stepper coils. I swapped out for a new stepper motor, redid my wiring according to [this post](https://github.com/thehookup/Motorized_MQTT_Blinds/issues/40#issuecomment-1156792619) because it seems the driver pin mappings have been updated since 2019, and bob's yur uncle! To check if you have fried coil, measure the resistance on both coils. They should be the same. If one of them reads different you have a fried coil and it's ready for the trashcan.

BzowK, 2022-08-10:
Thanks.  I tried a new motor, but got the same results.  Odd  Will test + give another shot soon and post results.  Thanks!

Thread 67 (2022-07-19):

Motor Still Not Turning

softtechs1, 2022-07-19:
@thehookup I purchased everything from the amazon links and wired as in the pic schematic. Using the 12v power supply, connected to the input side of the buck converter. Ran another 12v wire pair to connect the DRV8825’s UMOT/GRN pins. NodeMCU 12E gets power from the buck’s 6V output side. From the buck converter output side, I also have another 6V pair, which only the + from the buck converter is connected to the DRV8825 FLT pin, the negative is not connected as per the schematic, which is confusing. Everything else the schematic should be straight forward (Step, Dir, EN and 4 Motor wires). From what’s in the schematic, I don’t understand how the grounds tie together?

Sketch uploaded to NodeMCU, Got MQTT & HA Working. Searching for answers for 3 days now. Thanks!

See my test bench photos
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

softtechs1, 2022-07-20:
After 3 days, I got the motor turning by replacing my third DRV8825 and using jumper on the RST & SLP pins instead of soldering.  I did notice I "may" have not dug deep enough to clear the center trace from the motor that could have cause issues. Now the motor turns using the HA MQTT script, however it's very choppy and not going full rotations. Any input will help?

Closed 2022-07-21.

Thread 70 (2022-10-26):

Erratic Movement - Only using Blinds_CONFIGURE.ino code

RoninATX, 2022-10-26:
Got the parts, got everything connected, and even got the motors to behave correctly in a very simple test harness loop that is capable of moving the motor FORWARD and BACKWARDS reliably using either Stepper.move() or Stepper.revolve()

However when we run the provided code, the MQTT side appears to be functioning properly (e.g. OPEN and CLOSE messages in /blindsCommand publishing the appropriate 0 and 12 integer messages to /positionCommand), and in the diagnostic ouput we can even watch the interim positions step up 0-1-2-3-4-etc and down 12-11-10-9-etc, but the corresponding motor movements are erratic.  On the same command, it might do two or three steps in the correct direction, then stutter back in the opposite direction for a step, then even resume in the correct direction.

As a test, we tried modifying the original movement blocks (i.e.)

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

to something like this:

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

And then a similar approach for the BACKWARD movement code block.

Basically, rather than going through a repeating 12 step loop between newPosition and currentPosition to drive OPEN and CLOSE commands, we instead want to test fire a 5 pulse FORWARD movement with 1 second between pulses, and then "drop out" of the loop by equaling out newPosition and currentPosition, so the code only executes once per OPEN or CLOSE command.

The expected result works fine. When I hit OPEN, I count 5 distinct movement bursts in the correct direction on the motor. When I hit CLOSE, I count 5 distinct movement bursts in the opposite direction on the motor. This behavior ends up working correctly with over 5 min of OPEN and CLOSE alternating commands.

Take the same code, and instead let it go back to doing the whole currentPosition++/currentPosition--, single Stepper.move() call, and it goes back to unpredictably changing directions.

Near as I can tell, there seems to be something wonky going on in how the stacked Stepper.move() commands buffer out to the driver, where perhaps there's some kind of... latency? or +/- loss in the direction that ends up getting passed? I don't know. Not sure what else to do or check.

RoninATX, 2022-10-27:
Update (and Closing this issue)

After wrestling with this for a couple more hours, we decided to start swapping out components and discovered that some motors were able to behave correctly in _both_ the live code and the test harness code.  We discovered that out of 12 or so motors that we bought, only 5 were able to drive in the correct directions, while the remaining (and our original specimen) have the erratic back-and-forth steps along the OPEN / CLOSE commands.

The fact that the "failed" motors still seemingly turn correctly when pausing between individual position steps (test harness) is still baffling, it's almost like a continuous stream of FORWARD / BACKWARD overloads something in the motor's chip or something.

Anyhow, TL;DR - if this is happening to you, try swapping out motors.

Closed 2022-10-27.

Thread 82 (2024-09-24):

1 rotation from stepper motor needed

KoenVoortman, 2024-09-24:
Hi, noob/novice MQTT and Arduino user here.

I have a Homebridge installation with an embedded MQTT broker (Aedes) and a Mqttthing plugin for devices.
That part is working, and I have connection with my NodeMCU and I can control the stepper motor.

I'm in the Netherlands and have Veneta 50mm horizontal/venetian blinds.
I've re-designed a housing for the stepper motor, driver, NodeMCU and power converter, that will fit in the blinds housing, see pictures below.

My problem is: the full open to closed is 1 rotation of the hexagon axis in the blinds housing.
How/where do I adjust settings in the code, so the stepper motor will only rotate 1 time (1x 360 degrees) when I send a 0<->100 command?
I've played with the settings in the Arduino code, and there are limited options in the MQTT code in Homebridge.

I hope somebody can help!

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

Sander1978-dev, 2025-01-30:
Hi Koen, I am currently printing it for the Veneta blinds (60mm) to see if it fits, can you share your STL please? That way I can see if it fits for me and I can try to reproduce it and fix it for you

KoenVoortman, 2025-01-30:
Hi Sander,

This is the most recent version. The holes are for "cooling" and routing wires internally.

I'm curious if you can fix it! Thanks!

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

[HorizontalBlindsMotorHousing_KVO_v7.stl.zip](https://github.com/user-attachments/files/18608872/HorizontalBlindsMotorHousing_KVO_v7.stl.zip)

Sander1978-dev, 2025-01-31:
Thank you, I just started printing it and will look at the code. I have also found this discussion (in Dutch) https://gathering.tweakers.net/forum/list_messages/2207606

with the corresponding github: https://github.com/Hordica/ESPHome-smart-shutter-tilt

However, that 3D model is for the old Veneta blinds and it uses microswitches to detect begin and end. That way it wont rotate further then needed. So the code and microswitches could be useful.

I have that code and hardware connected, however no 3D model for it yet. I will try to see if I can get best from both worlds and will respond here when I got it working.

Sander1978-dev, 2025-01-31:
Hi Koen, I have looked at the code and have you tried modifying the line
`position_closed: 12` to `position_closed: 3`

I devided it by 4 since you say it does 4 rotations.

Your mod fits perfectly in my veneta 60mm blinds, however I have used a 5V stepper motor from the project I mentioned above instead of this project mentioning a 12V stepper motor. The 5V stepper motor doesnt have the power to turn the axis.

KoenVoortman, 2025-02-11:
Hi Sander, yes I think I’ve tried.
Several settings actually.
Will try again in a few weeks maybe. Kinda busy now.

Good to hear the housing fits in your Veneta also!
I’ve gone through some versions ;)
This was V1 through 5 😊
Made some minor adjustments after those.

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

Sander1978-dev, 2025-03-28:
Hi Koen, today I finally got time to try the 12V setup. But even the 12V stepper motor is unable to turn my blinds. Only difference I see in the blinds is that you have the band where I have small wires connected to the horizontal blades. Did you remove the box insde the blinds where the manual control cables are?

KoenVoortman, 2025-03-30:
Hi, I have no problems with my 50mm ones. Just have to find time to finish 8 modules to complete all my blinds.

And yes, you need to remove the original manual control box. This is your problem I think.
I've put my modules on that spot in the base.

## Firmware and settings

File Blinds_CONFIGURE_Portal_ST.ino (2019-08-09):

#define USE_WIFIMANAGER
#define AP_NAME "ST Blinds Config"
#define ST_HUB_IP 192.168.86.70
/******************  ALEXA INTEGRATION LIBRARIES *************************************/
#include <SmartThingsESP8266WiFi.h>
#include <ESP8266mDNS.h>          //if you get an error here you need to install the ESP8266 board manager
/******************  WIFI MANAGER LIBRARIES *************************************/
#include <FS.h>  
#include <DNSServer.h>
#include <ESP8266WebServer.h>
#include <WiFiManager.h>          //https://github.com/tzapu/WiFiManager
#include <ArduinoJson.h>          //https://github.com/bblanchon/ArduinoJson//this needs to be first, or it all crashes and burns...
/******************  SKETCH SPECIFIC LIBRARIES *************************************/
#include <AH_EasyDriver.h>        //http://www.alhin.de/arduino/downloads/AH_EasyDriver_20120512.zip

/******************  BASIC PACKAGE LIBRARIES *************************************/
#include <SimpleTimer.h>          //https://github.com/thehookup/Simple-Timer-Library
#include <PubSubClient.h>         //https://github.com/knolleary/pubsubclient
#include <ESP8266WiFi.h>          //if you get an error here you need to install the ESP8266 board manager 
#include <ESP8266mDNS.h>          //if you get an error here you need to install the ESP8266 board manager 
#include <ArduinoOTA.h>           //ArduinoOTA is now included with the ArduinoIDE

/*****************  START USER CONFIG SECTION *********************************/
/*****************  START USER CONFIG SECTION *********************************/
/*****************  START USER CONFIG SECTION *********************************/
/*****************  START USER CONFIG SECTION *********************************/

//define your default values here, if there are different values in config.json, they are overwritten.
SmartThingsCallout_t messageCallout;    // call out function forward decalaration
IPAddress smartthings_hub_ip;
char char_hub_ip[20];
char rotations[6];
char current_position[6] = "0";
const unsigned int serverPort = 8090; // port to run the http server on
const unsigned int hubPort = 39500;
String string_hub_ip;
unsigned long send_rotations;

#define STEPPER_SPEED             35                  //Defines the speed in RPM for your stepper motor
#define STEPPER_STEPS_PER_REV     1028                //Defines the number of pulses that is required for the stepper to rotate 360 degrees
#define STEPPER_MICROSTEPPING     0                   //Defines microstepping 0 = no microstepping, 1 = 1/2 stepping, 2 = 1/4 stepping 
#define DRIVER_INVERTED_SLEEP     1                   //Defines sleep while pin high.  If your motor will not rotate freely when on boot, comment this line out.


#define STEPPER_DIR_PIN           D6
#define STEPPER_STEP_PIN          D7
#define STEPPER_SLEEP_PIN         D5
#define STEPPER_MICROSTEP_1_PIN   14
#define STEPPER_MICROSTEP_2_PIN   12
 
/*****************  END USER CONFIG SECTION *********************************/
/*****************  END USER CONFIG SECTION *********************************/
/*****************  END USER CONFIG SECTION *********************************/
/*****************  END USER CONFIG SECTION *********************************/
/*****************  END USER CONFIG SECTION *********************************/

WiFiClient espClient;
PubSubClient client(espClient);
SimpleTimer timer;
AH_EasyDriver shadeStepper(STEPPER_STEPS_PER_REV, STEPPER_DIR_PIN ,STEPPER_STEP_PIN,STEPPER_MICROSTEP_1_PIN,STEPPER_MICROSTEP_2_PIN,STEPPER_SLEEP_PIN);
st::SmartThingsESP8266WiFi smartthing(serverPort, ST_HUB_IP, hubPort, messageCallout);

//Global Variables
bool shouldSaveConfig = false;
bool boot = true;
int currentPosition = 0;
int newPosition = 0;
bool moving = false;
char positionPublish[50];

void messageCallout(String message)
{
  if (message.equals("on"))
  {
    smartthing.send("on");        // send message to cloud
    newPosition = send_rotations;
  }
  else if (message.equals("off"))
  {
    smartthing.send("off");       // send message to cloud
    newPosition = 0;
  }
}

#ifdef USE_WIFIMANAGER
void saveConfigCallback() 
{
  Serial.println("Should save config");
  shouldSaveConfig = true;
}

void configPortal()
{
  Serial.println("mounting FS...");
  if (SPIFFS.begin()) 
  {
    Serial.println("mounted file system");
    
    //RECALL PROGRAM SPECIFIC SAVED VARIABLES
    
    if (SPIFFS.exists("/storedPosition.json"))
    {
      File storedFile = SPIFFS.open("/storedPosition.json", "r");
      if (storedFile) 
      {
        Serial.println("opened config file");
        size_t size = storedFile.size();
        // Allocate a buffer to store contents of the file.
        std::unique_ptr<char[]> buf(new char[size]);
        storedFile.readBytes(buf.get(), size);
        DynamicJsonBuffer jsonBuffer;
        JsonObject& json = jsonBuffer.parseObject(buf.get());
        json.printTo(Serial);
        if (json.success()) 
        {
          Serial.println("\nparsed json");
          strcpy(current_position, json["current_position"]);
          String tempPos = String((char *)current_position);
          currentPosition = tempPos.toInt();
          newPosition = tempPos.toInt();
          boot = false;
         } 
        else 
        {
          Serial.println("failed to load json config");
        }
      }
    }

    //RECALL WIFIMANAGER SPECIFIC VARIABLES
    
    if (SPIFFS.exists("/config.json")) 
    {
      Serial.println("opened wificonfig file");
      File configFile = SPIFFS.open("/config.json", "r");
      if (configFile) 
      {
        Serial.println("opened config file");
        size_t size = configFile.size();
        // Allocate a buffer to store contents of the file.
        std::unique_ptr<char[]> buf(new char[size]);
        configFile.readBytes(buf.get(), size);
        DynamicJsonBuffer jsonBuffer;
        JsonObject& json = jsonBuffer.parseObject(buf.get());
        json.printTo(Serial);
        if (json.success()) 
        {
          Serial.println("\nparsed json");
          strcpy(char_hub_ip, json["char_hub_ip"]);
          strcpy(rotations, json["rotations"]);
        } 
        else 
        {
          Serial.println("failed to load json config");
        }
      }
    }
  } 
  else 
  {
    Serial.println("failed to mount FS");
  }

  //SPECIFIC PARAMETERS TO BE CONFIGURED IN WIFI MANAGER GO HERE
  //ORDER IS (ID, PLACEHOLDER TEXT, VARIABLE TO FILL, DEFAULT LENGTH

  WiFiManagerParameter custom_smartthings_hub_ip("ST_Hub_IP", "IP of your ST Hub", char_hub_ip, 20);
  WiFiManagerParameter custom_rotations("Rotations", "Number of rotations (12 recommended)", rotations, 6);

  WiFiManager wifiManager;
  wifiManager.setSaveConfigCallback(saveConfigCallback);
  
  //ADD A SPECIFIC PARAMETER FOR EACH PROMPT ABOVE
  wifiManager.addParameter(&custom_smartthings_hub_ip);
  wifiManager.addParameter(&custom_rotations);

  //RESET STORED VARIABLES IF PIN D1 IS PULLED LOW
  if(digitalRead(D1) == LOW)
  {
    wifiManager.resetSettings();
  }
  
  //THIS STARTS THE AP
  if (!wifiManager.autoConnect(AP_NAME)) 
  {
    Serial.println("failed to connect and hit timeout");
    delay(3000);
    //reset and try again, or maybe put it to deep sleep
    ESP.reset();
    delay(5000);
  }

  //THIS HAPPENS IF THERE IS A SUCCESSFUL WIFI CONNECTION
  Serial.println("connected...");

  //GRAB THE VALUES FROM THE INPUTS AND SAVE TO VARIABLES
  strcpy(char_hub_ip, custom_smartthings_hub_ip.getValue());
  string_hub_ip = String(char_hub_ip);
  smartthings_hub_ip.fromString(string_hub_ip);
  strcpy(rotations, custom_rotations.getValue());
  send_rotations = strtoul(rotations, NULL, 10);
  
  //PUT THE VALUES FROM THE INPUTS INTO SPIFFS
  if (shouldSaveConfig) 
  {
    Serial.println("saving config");
    DynamicJsonBuffer jsonBuffer;
    JsonObject& json = jsonBuffer.createObject();
    json["char_hub_ip"] = char_hub_ip;
    json["rotations"] = rotations;
    File configFile = SPIFFS.open("/config.json", "w");
    if (!configFile) 
    {
      Serial.println("failed to open config file for writing");
    }
    json.printTo(Serial);
    json.printTo(configFile);
    configFile.close();
  }
}
#endif

void processStepper()
{
  if (newPosition > currentPosition)
  {
    #if DRIVER_INVERTED_SLEEP == 1
    shadeStepper.sleepON();
    #endif
    #if DRIVER_INVERTED_SLEEP == 0
    shadeStepper.sleepOFF();
    #endif
    shadeStepper.move(80, FORWARD);
    currentPosition++;
    moving = true;
  }
  if (newPosition < currentPosition)
  {
    #if DRIVER_INVERTED_SLEEP == 1
    shadeStepper.sleepON();
    #endif
    #if DRIVER_INVERTED_SLEEP == 0
    shadeStepper.sleepOFF();
    #endif
    shadeStepper.move(80, BACKWARD);
    currentPosition--;
    moving = true;
  }
  if (newPosition == currentPosition && moving == true)
  {
    #if DRIVER_INVERTED_SLEEP == 1
    shadeStepper.sleepOFF();
    #endif
    #if DRIVER_INVERTED_SLEEP == 0
    shadeStepper.sleepON();
    #endif
    String temp_str = String(currentPosition);
    temp_str.toCharArray(positionPublish, temp_str.length() + 1);
    Serial.println("saving position");
    DynamicJsonBuffer jsonBuffer;
    JsonObject& json = jsonBuffer.createObject();
    json["current_position"] = positionPublish;

    File storedFile = SPIFFS.open("/storedPosition.json", "w");
    if (!storedFile) {
      Serial.println("failed to open config file for writing");
    }
    json.printTo(Serial);
    json.printTo(storedFile);
    storedFile.close();
    
    moving = false;
  }
  Serial.println(currentPosition);
  Serial.println(newPosition);
}

//Run once setup
void setup() {
  pinMode(D1, INPUT_PULLUP);
  Serial.begin(115200);
  configPortal();
  string_hub_ip = String(char_hub_ip);
  smartthings_hub_ip.fromString(string_hub_ip);
  Serial.print("SmartThings Hub IP Set From WiFi Manager: ");
  Serial.println(smartthings_hub_ip);
  shadeStepper.setMicrostepping(STEPPER_MICROSTEPPING);            // 0 -> Full Step                                
  shadeStepper.setSpeedRPM(STEPPER_SPEED);     // set speed in RPM, rotations per minute
  #if DRIVER_INVERTED_SLEEP == 1
  shadeStepper.sleepOFF();
  #endif
  #if DRIVER_INVERTED_SLEEP == 0
  shadeStepper.sleepON();
  #endif
  WiFi.mode(WIFI_STA);
//  ArduinoOTA.setHostname();
//  ArduinoOTA.begin(); 
  delay(10);
  smartthing.init();
  if(currentPosition == 0)
  {
    smartthing.send("off");
  }
  else if(currentPosition == send_rotations)
  {
    smartthing.send("on");
  }
  timer.setInterval(((1 << STEPPER_MICROSTEPPING)*5800)/STEPPER_SPEED, processStepper);   

}

void loop() 
{
  smartthing.run();
//  ArduinoOTA.handle();
  timer.run();
}

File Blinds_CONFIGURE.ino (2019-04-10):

#include <SimpleTimer.h>    //https://github.com/marcelloromani/Arduino-SimpleTimer/tree/master/SimpleTimer
#include <ESP8266WiFi.h>    //if you get an error here you need to install the ESP8266 board manager 
#include <ESP8266mDNS.h>    //if you get an error here you need to install the ESP8266 board manager 
#include <PubSubClient.h>   //https://github.com/knolleary/pubsubclient
#include <ArduinoOTA.h>     //https://github.com/esp8266/Arduino/tree/master/libraries/ArduinoOTA
#include <AH_EasyDriver.h>  //http://www.alhin.de/arduino/downloads/AH_EasyDriver_20120512.zip

/*****************  START USER CONFIG SECTION *********************************/
/*****************  START USER CONFIG SECTION *********************************/
/*****************  START USER CONFIG SECTION *********************************/
/*****************  START USER CONFIG SECTION *********************************/

#define USER_SSID                 "YOUR_SSID"
#define USER_PASSWORD             "YOUR_WIFI_PASSWORD"
#define USER_MQTT_SERVER          "YOUR_MQTT_SERVER_ADDRESS"
#define USER_MQTT_PORT            1883
#define USER_MQTT_USERNAME        "YOUR_MQTT_USER_NAME"
#define USER_MQTT_PASSWORD        "YOUR_MQTT_PASSWORD"
#define USER_MQTT_CLIENT_NAME     "BlindsMCU"         // Used to define MQTT topics, MQTT Client ID, and ArduinoOTA

#define STEPPER_SPEED             35                  //Defines the speed in RPM for your stepper motor
#define STEPPER_STEPS_PER_REV     1028                //Defines the number of pulses that is required for the stepper to rotate 360 degrees
#define STEPPER_MICROSTEPPING     0                   //Defines microstepping 0 = no microstepping, 1 = 1/2 stepping, 2 = 1/4 stepping 
#define DRIVER_INVERTED_SLEEP     1                   //Defines sleep while pin high.  If your motor will not rotate freely when on boot, comment this line out.

#define STEPS_TO_CLOSE            12                  //Defines the number of steps needed to open or close fully

#define STEPPER_DIR_PIN           D6
#define STEPPER_STEP_PIN          D7
#define STEPPER_SLEEP_PIN         D5
#define STEPPER_MICROSTEP_1_PIN   14
#define STEPPER_MICROSTEP_2_PIN   12
 
/*****************  END USER CONFIG SECTION *********************************/
/*****************  END USER CONFIG SECTION *********************************/
/*****************  END USER CONFIG SECTION *********************************/
/*****************  END USER CONFIG SECTION *********************************/
/*****************  END USER CONFIG SECTION *********************************/

WiFiClient espClient;
PubSubClient client(espClient);
SimpleTimer timer;
AH_EasyDriver shadeStepper(STEPPER_STEPS_PER_REV, STEPPER_DIR_PIN ,STEPPER_STEP_PIN,STEPPER_MICROSTEP_1_PIN,STEPPER_MICROSTEP_2_PIN,STEPPER_SLEEP_PIN);

//Global Variables
bool boot = true;
int currentPosition = 0;
int newPosition = 0;
char positionPublish[50];
bool moving = false;
char charPayload[50];

const char* ssid = USER_SSID ; 
const char* password = USER_PASSWORD ;
const char* mqtt_server = USER_MQTT_SERVER ;
const int mqtt_port = USER_MQTT_PORT ;
const char *mqtt_user = USER_MQTT_USERNAME ;
const char *mqtt_pass = USER_MQTT_PASSWORD ;
const char *mqtt_client_name = USER_MQTT_CLIENT_NAME ; 




//Functions
void setup_wifi() {
  // We start by connecting to a WiFi network
  Serial.println();
  Serial.print("Connecting to ");
  Serial.println(ssid);

  WiFi.begin(ssid, password);

  while (WiFi.status() != WL_CONNECTED) {
    delay(500);
    Serial.print(".");
  }

  Serial.println("");
  Serial.println("WiFi connected");
  Serial.println("IP address: ");
  Serial.println(WiFi.localIP());
}

void reconnect() 
{
  int retries = 0;
  while (!client.connected()) {
    if(retries < 150)
    {
      Serial.print("Attempting MQTT connection...");
      if (client.connect(mqtt_client_name, mqtt_user, mqtt_pass)) 
      {
        Serial.println("connected");
        if(boot == false)
        {
          client.publish(USER_MQTT_CLIENT_NAME"/checkIn","Reconnected"); 
        }
        if(boot == true)
        {
          client.publish(USER_MQTT_CLIENT_NAME"/checkIn","Rebooted");
        }
        // ... and resubscribe
        client.subscribe(USER_MQTT_CLIENT_NAME"/blindsCommand");
        client.subscribe(USER_MQTT_CLIENT_NAME"/positionCommand");
      } 
      else 
      {
        Serial.print("failed, rc=");
        Serial.print(client.state());
        Serial.println(" try again in 5 seconds");
        retries++;
        // Wait 5 seconds before retrying
        delay(5000);
      }
    }
    if(retries > 149)
    {
    ESP.restart();
    }
  }
}

void callback(char* topic, byte* payload, unsigned int length) 
{
  Serial.print("Message arrived [");
  String newTopic = topic;
  Serial.print(topic);
  Serial.print("] ");
  payload[length] = '\0';
  String newPayload = String((char *)payload);
  int intPayload = newPayload.toInt();
  Serial.println(newPayload);
  Serial.println();
  newPayload.toCharArray(charPayload, newPayload.length() + 1);
  if (newTopic == USER_MQTT_CLIENT_NAME"/blindsCommand") 
  {
    if (newPayload == "OPEN")
    {
      client.publish(USER_MQTT_CLIENT_NAME"/positionCommand", "0", true);
    }
    else if (newPayload == "CLOSE")
    {   
      int stepsToClose = STEPS_TO_CLOSE;
      String temp_str = String(stepsToClose);
      temp_str.toCharArray(charPayload, temp_str.length() + 1);
      client.publish(USER_MQTT_CLIENT_NAME"/positionCommand", charPayload, true);
    }
    else if (newPayload == "STOP")
    {
      String temp_str = String(currentPosition);
      temp_str.toCharArray(positionPublish, temp_str.length() + 1);
      client.publish(USER_MQTT_CLIENT_NAME"/positionCommand", positionPublish, true); 
    }
  }
  if (newTopic == USER_MQTT_CLIENT_NAME"/positionCommand")
  {
    if(boot == true)
    {
      newPosition = intPayload;
      currentPosition = intPayload;
      boot = false;
    }
    if(boot == false)
    {
      newPosition = intPayload;
    }
  }
  
}
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

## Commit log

2019-05-22 Fixed hex connectors
    [Adjusted 5mm Connector.stl, Adjusted 6mm Connector.stl]
2020-03-03 Add 6mm square adapter plus openscad project
    Add adapter for 6mm square tilt rod, together with the scad file to
    create it in case it is useful for creating other variants.
    [BlindsAdapter.scad, BlindsAdapter6mmSquare.stl]
2020-07-08 OpenSCAD file created by dsandor
    [BlindsBase.scad]
2021-05-22 Additional Bases
    [BlindsBaseShort.stl, BlindsBaseShortLong.stl]
2021-07-27 Add files via upload
    Gerber Files for 3 Blinds Sender and Receiver PCB
2021-07-27 Add files via upload
    User Submitted PCBs
2021-09-09 Added 123jaloezie base
    [123jaloezie-base.stl]
